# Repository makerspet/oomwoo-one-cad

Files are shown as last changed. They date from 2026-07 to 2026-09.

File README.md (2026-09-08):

<div align="center">

# OOMWOO One CAD

*Open-source robot vacuum you build yourself.*

3D CAD · STEP · 3D printable · Chassis · Mounts · Open hardware





</div>

DIY build instructions [will be posted here](https://makerspet.com/blog/oomwoo-vacuum-build-instructions/). Please visit project home [OOMWOO](https://github.com/makerspet/oomwoo).

## Active work in progress

oomwoo_base_sept_7

side_brush_reverse_engineered

vacuum_assembly_reverse_engineered

## Dock concept

oomwoo_dock_concept

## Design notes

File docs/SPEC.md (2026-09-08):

OOMWOO One open-source vacuum robot spec

A brain-dump with some explanations. First of all, there are 3 living documents

- BOM.md https://github.com/makerspet/oomwoo/blob/main/BOM.md
- Companion article https://makerspet.com/blog/how-to-source-bom-for-oomwoo-open-source-vacuum-robot/
- 3D design spec https://github.com/makerspet/oomwoo-one-cad/blob/main/docs/SPEC.md

All 3D CAD design files live in this repo https://github.com/makerspet/oomwoo-one-cad

Let me go over each component and explain the thinking about it. Please let me know any comments/questions.

I will list the "recommended selection" as well as "backup alternatives".

- "Drive wheel assembly pair". Recommended - reuse Roborock S5 Max wheels because they are abundant in the aftermarket https://makerspet.com/blog/how-to-source-bom-for-oomwoo-open-source-vacuum-robot/#driving-wheels There is a backup alternative - Roborock S5 (non-Max) wheels. These are also abundant, but older. So, don't use those, lets stick with Roborock S5 Max.
- "Caster wheel". Recommended - caster wheel off iRobot Roomba I3/4/6/8, J7/Plus J7 E5/6 500 600 700 800 900 series. It appears to be the most abundant in the aftermarket. iRobot has used the same caster part using in all those models over years. Backup alternatives - plenty available off-the-shelf on AliExpress; or 3D print using TPU.
- "Suction fan". Recommended - BL24131616 10kPa. Recommended for 2nd vacuum version - 36 kPa from Roborock Saros 20, . Backup alternatives - fans with lower suction. Why 10kPa - modern vacuums use increasingly stronger suction. Old vacuums use mere 2-2.5kPa. Users want to see bigger kPa suction.
- "Main brush". Recommended - "Anti-tangle split single roller, rubber and bristles" for Roborock Saros. Users *strongly* want no tangling at all. This roller type seems one of the best - but *I may be wrong*. Another roller that appears to be great is "Anti-tangle hair-cutting dual roller, rubber and bristles", sold as replacement for Dreame vacuums. Please read about roller choices here https://makerspet.com/blog/how-to-source-bom-for-oomwoo-open-source-vacuum-robot/#main-brush Another option is 2 rollers, but having 2 rollers (I assume) will complicate your CAD design. So single (or single split?) roller seems best for 1st vacuum version. The 1st vacuum version's name is OOMWOO One.
- "Battery pack + BMS". Required - the standard Roborock battery. Roborock has been using it over many years and many models. It comes with built-in protection and thermistor. No obvious alternatives.
- "2D LiDAR". Recommended - "PCB mark X-WPFTB-V2.6.2, possibly Camsense". However, there are many alternatives. Some users own different LiDARs - and want to reuse them. So, we should let users pick their LiDAR - by 3D printing a custom mounting bracket.
- "Compute Module". Required - Raspberry Pi CM4 or CM5. CM4 and CM5 have identical dimensions.
- "I/O board". Required - custom-designed PCB https://github.com/makerspet/oomwoo-io-board. The I/O board will have all motor/sensor connectors, driver ICs. The "Compute Module" will plug into the I/O board. The I/O board shape/dimensions is *not* set - it will be decided based on your CAD design.
- "Cliff sensors". Required - "cliff sensor + bumper switches bundle" iRobot Roomba 500 600 700 800 528 552 564 595 560 570 610 615 620 625 630 650 off-the-shelf, abundant in the aftermarket. The "bundle" includes 4 IR cliff sensors and 2 bumper switch assemblies. Backup alternatives - if this bundle doesn't work for you, let me know, I will suggest alternatives. Please note - some vacuums have 4 IR cliff sensors, while others have 6. The typical 4-sensor placement is (1) around the caster wheel (in the front) and in front of each driving wheel. 6-sensor vacuums add one sensor just behind each driving wheel. I've noticed some vacuums have 5 sensors (only one driving wheel has 2 cliff sensors). Generally, I'd like to have 6 cliff sensors, but 6-sensor bundles are harder to find/purchase.
- "Bumper switches". Required - please use the iRobot bundle. If you find a problem using these - let me know.
- "Main brush motor, gearbox". Required - let's use one off Roborock S5 because it is abundant. However, this assembly fits Roborock brushes with bristles (which tangle hair badly). So, you may need to design some sort of adapter to accommodate tangle-free brushes. Backup alternatives - we can buy the DC motor and 3D print gears using an SLA resin printer. But I'd like to avoid this additional complexity if possible. FYI, commercial vacuums use RS390 and RS395 DC motors.
- "Side brush". Recommended - "2-arm curved" side brush from Roborock Saros. It seems better at anti-tangling (but I haven't checked). Backup alternatives - older Roborock side brushes or Dreame side brushes.
- "Side brush motor". Recommended - only one side brush, extendable, from Roborock Qrevo https://www.alibaba.com/product-detail/Roborock-Telescopic-Robotic-Arm-Side-Brush_1601598853246.html Backup alternatives - if the recommended one doesn't work for you, let me know, I will check Dreame X40 and Dreame X50 extendable side brush assemblies.
- "Wall sensor". Required - two little custom-designed PCB (one left, one right). These sensors (1) detect IR signal from the dock (2) detect wall (in a crude way). Backup alternative - a Roborock wall sensor assembly is available on AliExpress, but not abundant.
- "Dock homing sensor". Required - a little custom-designed PCB with two IR sensors, in vacuum rear front. Backup alternatives - let me know if there is a problem and I will check.
- "Carpet sensor". Required - ultrasonic 300kHz material sensor, fixed 30mm distance above floor. This model for your initial CAD design https://www.aliexpress.us/item/3256808845934210.html and this model for volume https://htwsensor.en.made-in-china.com/product/jARpDPKoaxVz/China-300kHz-Carpet-Material-Recognition-Sensor-for-Robotic-Vacuum-Cleaner-Ultraosinc-Sensor-Transducer.h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 .
- "Charging contacts" (on the robot). Recommended - DIY using a nickel-plated steel strip (purchased on AliExpress). Located in the robot's rear around the homing IR sensor PCB. No springs. Strip width/length - up to you. AliExpress has 10-12mm. Each contact (positive, ground) connects to a PCB connector cable. The contact-to-wire connection could be accomplished by designing a tiny 3D printed "terminal'. Have a machine screw pressing the (stripped) wire against the strip.
- "Mop motor assembly". Recommended - 2 rotary/disk mops. One static, one extendable. Use Roborock Qrevo FlexiArm https://www.alibaba.com/product-detail/Mop-Deceleration-Motor-Retractable-Mopping-Module_1601599652498.html Backup alternatives - if the Roborock Qrevo doesn't work for you, I can search Chinese ODM making Dreame MopExtend.
- "Obstacle avoidance camera". Recommended - 1x front-facing OV5647 with a 16-pin flexible cable, ~130 degree FOV. Backup alternatives - none that are cheap.
- Bagless vs bag dock. Recommendation: bagless. Why? Multiple users requested bagless; no-one asked for bags. Also, no consumable bag purchase/cost. The dock's dust bin can be 3D printed. However, bagged is easier to engineer. Bagless needs reliable separation (a working cyclone + washable filter). Designing a good cyclone is important. A poor one sends fine dust straight to the filter, clogs the filter, and suction dies.
Auto-empty design. Recommendation: bottom extraction (Roborock style). Why? This is what my Claude says:
- side brush with extensible arm assembly - expensive, hard to find retail. Roborock uses lots of gears; the brush DC motor both actuates the brush and the arm. Design from scratch using a little timing belt, aluminum timing pulleys and a geared DC motor (metal gearbox comes with the motor). 3D-print the assembly enclosure This avoids having to 3D print gears and keeps the build inexpensive.

=== Claude =====================================

1. Gravity is on your side. Dust settles to the bottom of the bin, and bottom extraction pulls it downward into the dock bin. A dedicated side/rear vent higher on the bin fights gravity — you're asking the fan to lift settled dust before it can carry it out.
2. Simplest robot-side port: one flap. You add a single spring/gravity trap door on the bin bottom — no second sealed opening in the bin. A dedicated vent means a second aperture you must seal against leaks during every vacuuming run.
3. Flat, forgiving dock mating. The dock side is just a gasketed hole in the base plate; the robot parks over it. Flat-plate-to-flat-plate tolerates alignment error far better than threading a nozzle into a port (which a dedicated vent requires). Your ramp/alcove already gets the robot "close enough," and a broad base port forgives the rest — same philosophy as oversizing the charging pads.
4. Proven and measurable. It's the dominant industry design, so you can study/measure a real Roborock dock to de-risk the printed geometry.
5. It decouples from your crowded rear. Your rear is already busy — vertical contacts + mop wash tray (back-in docking). Putting auto-empty on the underside keeps it spatially separate from that cluster.

The hard part is the same for both: the valve + the airflow path

Whichever port you choose, the real engineering is the flap valve and the makeup-air path, not the port location:

- The flap must do two contradictory things: seal tightly during vacuuming (so the robot's own fan doesn't lose suction through the auto-empty port) yet open freely under the dock's airflow. Bottom extraction makes this natural — the dock's downward suction pulls an inward/downward flap open, and spring + gravity reseat it. A high side/rear port needs a more deliberate valve.
- You must give the emptying airflow a makeup-air inlet, or the dock fan just pulls a vacuum against a sealed bin and moves nothing. The clean trick (and what Roborock does): let the dock's suction draw makeup air in through the robot's own intake mouth — which is right there at the bottom — so air sweeps through the bin and out the bottom port, entraining settled dust on the way. Design the bin so that emptying airflow traverses the whole bin volume rather than short-circuiting between two nearby openings. This is the single thing that determines whether auto-empty actually evacuates dust vs. just whistling.

Why not the dedicated bin vent

- Its only real advantage is a seal that's higher and away from floor-level dust. That's outweighed by: a second aperture to seal, a nozzle-to-port mating that's alignment-fussy, fighting gravity, and more total seals — all worse for a printed part where every seam is a potential leak. Not worth it.

Two build-specific notes

- Bagless synergy: bottom extraction drops dust straight down into the dock's printed bin sitting in the base — exactly what you want for the bagless, printed-container design you chose. Gravity does half the work of separating debris before the dock cyclone/filter even acts.
- Since the robot backs in rear-first (mop-dock orientation), position the dock base's suction hole under wherever the robot's bottom bin-port ends up in the docked position — likely forward of the mop/contact cluster. This is part of the same frozen dock interface as the contacts and the beacon, across all three tiers.

So: pull from underneath through a single bottom trap-door, let makeup air come in via the robot's intake so the flow sweeps the bin, and drop it into the printed dock bin by gravity. The dedicated-vent approach adds sealing complexity for a benefit you don't need.

Following modern (2026) consumer mop robot design, OOMWOO One requires

- one right front side brush (not two), with an extendable arm (swings out to the side to clean under cabinets)
- mop is 2-disk rotary (not roller for now); the right mop is extendable (swings out to the side to clean under cabinets); the left mop is fixed
- mop disks land into the dock tray (for mop washing, drying)
- having charging contacts on the *rear vertical face*
  - charging contacts cannot be on the robot's underside because this is where the mop wash tray sits
- vacuum *backing* into the (wash) dock (not driving in front-first)
- robot's dock homing sensor must be on the *rear vertical face* between the charging contacts
- robot's charging contacts are "dumb" (not spring-loaded), use an nickel-plated steel strip
  - nickel-plated steel strips resist corrosion, scratching
- charging contacts on the dock have to be spring loaded, with gold-plated pogo pins, 4A 20.1V to provide 65W
- TODO bagless or not
- LiDAR must be inset 10+cm from vacuum's enclosure edges
  - because LiDAR sensor has a ~10cm dead zone around it
- place LiDAR slightly off-vacuum-center
  - this allows capturing scans from new viewpoints while vacuum spins in-place without getting stuck (usually when lost to regain its whereabouts on the map)
- need to lift mops (when traveling over carpet) 12mm
- need a [carpet sensor](https://makerspet.com/blog/how-to-source-bom-for-oomwoo-open-source-vacuum-robot/#carpet-sensor) (ultrasonic ~300kHz) placed in front of main brush; carpet detect causes mops to lift, stop spinning, main brush to spin appropriately for carpet
  - carpet sensor detects carpet ahead of time as the vacuum travels forward, so the mop is always lifted over carpet
- need 2 side wall sensors (left, right)
  - wall sensors detect dock presence (by receiving IR signal from the dock) and act as a crude wall following (intensity based) sensor
  - wall sensor has to be a small custom PCB
- drving wheels should be centered, wide apart
  - let's try reusing [Roborock S5 Max assembly](https://makerspet.com/blog/how-to-source-bom-for-oomwoo-open-source-vacuum-robot/#driving-wheels) because it is abundant in the aftermarket
  - each wheel comes with a wheel drop sensor (a microswitch)
  - FYI some vacuums don't center driving wheels exactly
- robot-to-floor gap is largely defined by the drive wheels
- caster wheel - front center
  - let's try reusing the abundant [iRobot Roomba](https://makerspet.com/blog/how-to-source-bom-for-oomwoo-open-source-vacuum-robot/#caster-wheel)
- I/O board and compute module - front center top, shape TBD
  - board has pushbuttons
- battery pack - reuse abundant standard [Roborock battery pack](https://makerspet.com/blog/how-to-source-bom-for-oomwoo-open-source-vacuum-robot/#battery-pack)
  - place battery pack on the vacuum bottom, with an access door with screws, roughly under the I/O board or slightly behind, roughly centered to equalize pressure on both wheels and mops
  - TODO check if battery should be close to mops for cleaning pressure

## Dock

### Specs

- ~use an external certified 24 V DC brick (200–350 W)~
  - the dock only sees 24V?
  - inherit the brick's UL/CE certification?
  - ~reuse 25.2 V stick-vac motors, e.g. Dreame M10-E-4 (25.2 V, 310 W) handheld motor, use for auto-empty~
- power 1600W, see [X20 dock teardown](docs/dock_teardown_x20.pdf)
- ~dock contains USB PD sink, converts power to 20-24V charger contacts~
  - dock charger contacts check for robot's presence (resistance), enable power only when robot is present
- skip hot air dry, use a regular fan
  - Hot air dries the mop in ~2–3 h instead of ~6. But the robot sits docked for hours anyway.
  - Dropping the heater removes your biggest power draw and biggest thermal-safety risk.
- bagless
  - No consumable lock-in. The bin is a printed part.
  - Downside: emptying a dusty bin by hand. The dock bin is far larger than the robot's, so you empty it ~monthly instead of every run. Design a wide opening + lid to limit the dust puff.
  - Bagged is significantly easier to engineer — the bag is the container and the filter, so there's no cyclone to design.
  - Bagless needs real separation (a working cyclone + washable filter), and the cyclone is the main engineering risk of this choice — a poor one sends fines straight to the filter, it clogs, and suction dies.
  - Maybe prototype the auto-empty tier bagged to de-risk the port/sealing/motor work, then move to bagless once you've validated a cyclone geometry. Ship bagless.
- bottom extraction auto-empty
  - why? proven, Roborock style; gravity helps dust fall/evacuate vs non-bagless rise; only one, simple robot-side port, one flap - no sealed opening in the robot's dust bin needed; robot-to-dock flat plate-to-plate gasketed mating is relatively simple vs bagged nozzle-into-the-port mating; frees us space in the robot's rear
- tubing, see [X20 dock teardown](docs/dock_teardown_x20.pdf)
  - water 9mm OD clean, 11mm OD dirty, clean mop spray 6mm OD
  - air auto-empty ID 29mm OD 33mm
- canister present sensors: 2x (clear + dirty water canisters): magnet embedded into canister, hidden hall, see [X20 dock teardown](docs/dock_teardown_x20.pdf)
- water level sensors
  - clear water tank : floaters magnet/hall
- TBD sensors
  - TBD dock-side IR turbidity sensor
  - TBD thermistor + independent thermal fuse
  - TBD dock base leak/flood sensor
- TODO cleaning solution
- TBD hot water mop wash
- TBD hot air mop dry
- safety
  - Mains stays outside (certified brick)?
  - Physically separate wet section from electronics; drip loops, drainage, a dam/lip toward the contacts.
  - Presence-detect the robot, energize charge contacts only when the robot is docked
  - If using heater: redundant thermal cutoff (thermistor + independent thermal fuse), never fan-less.
  - Document as advanced build.

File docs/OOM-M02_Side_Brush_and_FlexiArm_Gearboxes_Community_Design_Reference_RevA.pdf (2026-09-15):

### OOMWOO ONE

# Side Brush & FlexiArm Gearboxes

## OOM-M02-02 / OOM-M02-03 / Community Design Reference

DOCUMENT TYPE
COMMUNITY DESIGN REFERENCE

REVISION
A

DATE

### 15 SEP 2026

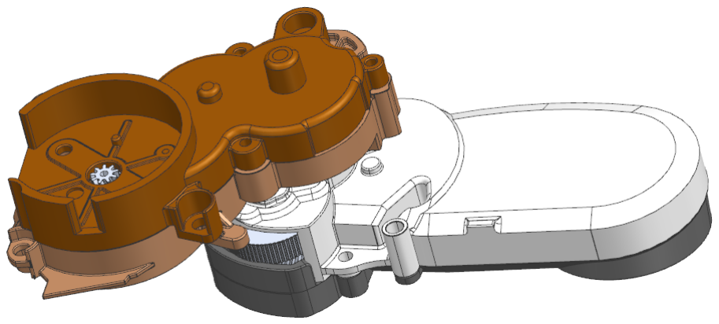
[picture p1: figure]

Figure 1. OOM-M02 side-brush module. The OOM-M02-03 brush gearbox and its motor (upper left, cover removed) are carried on the OOM-M02-02 FlexiArm extendable arm (right). The two housings meet at an angled joint.

Purpose. Explain the two gearboxes inside the OOM-M02 side-brush module for the OOMWOO One community: the OOM-M02-03 three-stage brush reduction (50.248:1), the OOM-M02-02 eleven-gear FlexiArm transfer train (39/14), their gear geometry, compound-axis logic, housing interfaces and the helical stages that carry torque through the arm joint.

COMMUNITY USE / Use this document together with the native CAD and STEP files. The tables explain the design intent and parameter relationships; the current repository CAD remains the master geometry for manufacturing, remixing or modification.

DATA STATUS / Revision A is built from two gear-parameter sheets, two motion studies and annotated CAD screenshots. Values are tagged VERIFIED when they reproduce from the source data, DERIVED when calculated in this document, and CONFIRM when they are an interpretation that must be checked against the CAD. Purchased bearing and bushing content is not identified in the source set and is left open in Section 7.

# 0 About This Design Reference

A practical engineering companion for understanding, rebuilding and modifying the two gearboxes of the OOM-M02 side-brush module.

OOMWOO One is an open-source robot vacuum project intended to be buildable, documented and hackable. The OOM-M02 module carries two independent gear trains with different jobs. OOM-M02-03 turns motor speed into brush speed at a high ratio; OOM-M02-02 routes rotation along the length of the extendable arm and through its angled joint at a ratio close to unity. This reference keeps the two separate so the ratio logic, the compound axes and the housing relationships stay easy to follow.

### How to use this document

Part-code traceability: custom components are identified by the project codes read from the CAD feature trees (Section 1.1). Codes that appear without a role label are listed as observed rather than guessed.
CAD-first reading: tooth counts, modules, pressure and helix angles and centre distances explain the design; the repository CAD/STEP geometry remains the manufacturing master.
Kinematic clarity: each gearbox has its own chain diagram, with compound (coaxial) members marked separately from external meshes so it is clear where torque changes shaft.
Explicit confidence: the three cover tags appear throughout. Nothing that could not be read from the source set is presented as a dimension.
Data review: Section 8 lists three internal inconsistencies found in the parameter sheets. Close those against the CAD before manufacturing or committing a remix.

### Design basis

ID | Design basis | Defines | Use here
B1 | OOM-M02 CAD / STEP set | Gear geometry, housing interfaces, shaft and support features | Manufacturing master
B2 | Gear parameter sheet, 31 AUG 2026 | OOM-M02-03 tooth counts, modules, pressure and helix angles, diameters, centre distances | Sections 2, 3
B3 | Gear parameter sheet, 02 SEP 2026 | OOM-M02-02 eleven-gear mesh list with diameters and centre distances | Sections 4, 5
B4 | Motion study, 01 SEP 2026 | OOM-M02-03 gear train running under a rotary motor driver | Compound-axis confirmation
B5 | Motion study, 03 SEP 2026 | Complete OOM-M02 module with the arm sectioned | Module architecture, joint geometry
B6 | Annotated CAD screenshots | Feature-tree part codes, gear position labels Z1- Z11 | Part numbering, position mapping
B7 | OOM-M03-01 reference, Rev B | Series document conventions and addendum/root formulae | Cross-module consistency

### Contents

Sec. | Topic | Page
1 | Module Architecture & Part Numbering | 3
1.1 | CAD Component Inventory | 4
2 | OOM-M02-03 Gear Train & Kinematics | 5
2.1 | Compound Axes & Load Path | 6
3 | OOM-M02-03 Gear Geometry Reference | 7
4 | OOM-M02-02 Architecture & Mesh List | 8
Sec. | Topic | Page
4.1 | Kinematic Chain & Telescoping Ratio | 9
5 | OOM-M02-02 Gear Geometry Reference | 10
6 | Helical Stages & the Arm Joint | 11
7 | Housing, Shaft & Support Architecture | 12
8 | Parameter-Sheet Consistency Review | 13
9 | Bill of Materials | 14
9.1 | Assembly & Manufacturing Notes | 15
10 | Community Build Notes | 16
10.1 | Open Items & References | 17

•

•

•

•

•

OOMWOO ONE / OOM-M02 SIDE BRUSH & FLEXIARM GEARBOXES

COMMUNITY DESIGN REFERENCE | REV A | 15 SEP 2026 | 2

# 1 Module Architecture & Part Numbering

Two gearboxes, two housings and one angled joint: a high-ratio brush drive carried on a near-unity transfer train that reaches along the extendable arm.

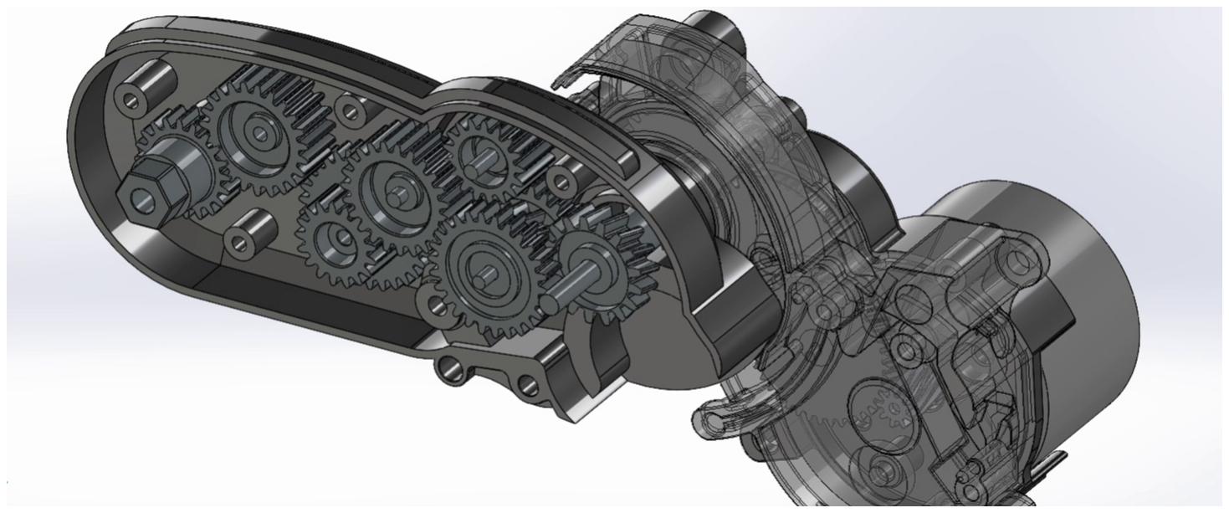
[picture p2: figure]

Figure 2. Complete OOM-M02 module from the 03 SEP motion study. The OOM-M02-02 arm is sectioned to expose its eleven-gear train; the OOM-M02-03 brush gearbox and motor are shown transparent on the right. The gear plane of the arm and the gear plane of the brush module are not parallel, and the helical group sits at that break.

Part code | Designation | Type | Primary role
OOM-M02-01 | Module-level component | Custom part | Top-level member of the module assembly, outside both gear cavities. Role per CAD. CONFIRM
OOM-M02-02 | FlexiArm extendable arm gearbox | Sub-assembly, rev RV02 | Long oval two-shell housing carrying the eleven-gear transfer train Z1-Z11 and the external hex drive interface.
OOM-M02-03 | Side-brush motor gearbox | Sub-assembly, rev rv02 | Brush-side housing carrying the DC motor and the three- stage 50.248:1 reduction Z1-Z6.
OOM-M02-04 | Module-level component | Custom part, rev RV01 | Assembled together with OOM-M02-03 in the brush-side sub-assembly. Role per CAD. CONFIRM

TWO GEARBOXES, ONE MODULE / OOM-M02-03 is a reduction gearbox: three stages, 50.248:1, with the module rising along the train. OOM-M02-02 is a transfer gearbox: seven external meshes on the main branch that telescope to only 39/14 = 2.7857:1. Reading either one as if it were the other type leads to the wrong conclusions about tooth loading and backlash budget.

### Why the arm train is nearly unity

Eleven gears producing less than 3:1 look wasteful until the package is taken into account. The arm has to deliver rotation from one end of a long, slim, swinging housing to the other, then continue through a joint where the two gear planes break at an angle. The intermediate gears exist to relocate the torque path around bosses, the pivot and the housing wall, not to reduce speed. The same pattern appears in OOM-M03-01, where four spur meshes telescope to exactly 1.000 and the whole 3.091:1 comes from the helical input stage alone.
The practical consequence is that the intermediate gears in OOM-M02-02 all see roughly the same torque band, so the weakest tooth anywhere in the chain sets the limit rather than the last one. In OOM-M02-03 the opposite is true: torque rises by a factor of 50 from Z1 to Z6, which is why the module increases from 0.46 mm to 0.60 mm along the train.

# 1.1 CAD Component Inventory

Part codes exactly as they appear in the feature trees, with the gear-position mapping that follows from the tooth counts and instance quantities.

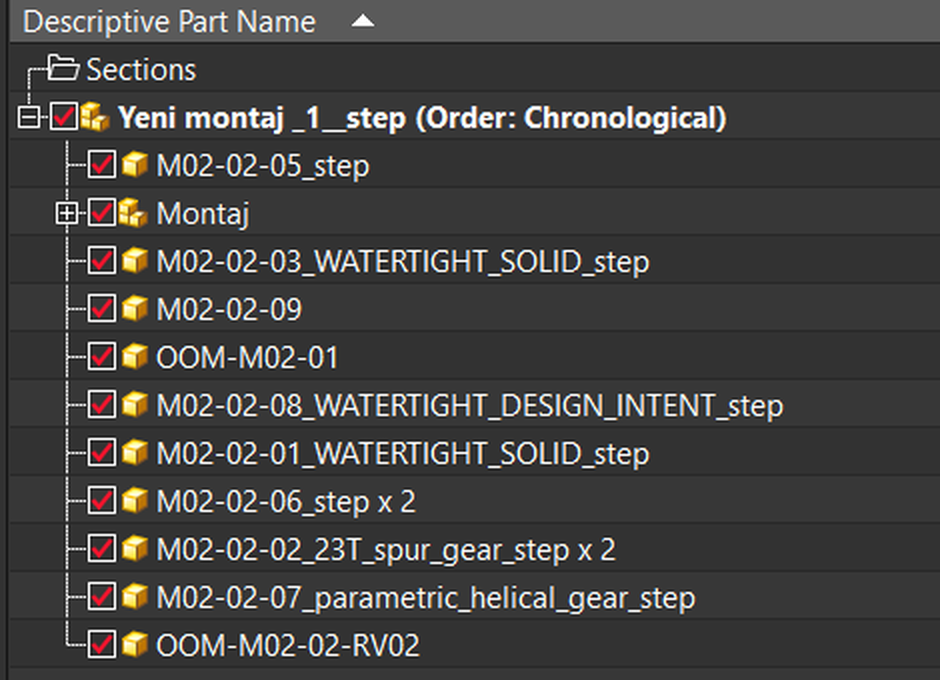
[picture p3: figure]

Figure 3. Component list of the OOM-M02 top-level assembly. Instance counts are significant: two 23T spur gear instances and two M02-02-06 instances match the repeated tooth counts in the parameter sheet.

### OOM-M02-02 FlexiArm gearbox components

Code as modelled | Qty | Read as | Basis
M02-02-01_WATERTIGHT_SOLID | 1 | Housing shell | Watertight reconstructed solid. CONFIRM
M02-02-02_23T_spur_gear | 2 | Z2 and Z5, 23T m0.6 | Only two 23T gears exist in the mesh list. DERIVED
M02-02-03_WATERTIGHT_SOLID | 1 | Housing shell | Second watertight solid. CONFIRM
M02-02-05 | 1 | Per CAD | In the tree with no descriptive suffix. CONFIRM
M02-02-06 | 2 | Z4 and Z6, 17T m0.6 | Only two 17T gears exist in the mesh list. DERIVED
M02-02-07_parametric_helical_gear | 1 | 17T helical, mn
| | 0.76 | Z10 and Z11 are geometrically identical; one parametric body covers both. DERIVED
M02-02-08_WATERTIGHT_DESIGN_INTENT | 1 | Housing / structural solid | Design-intent rebuild, not a scan solid. CONFIRM
M02-02-09 | 1 | Per CAD | In the tree with no descriptive suffix. CONFIRM

### OOM-M02-03 brush gearbox components

Code as modelled | Qty | Read as | Basis
OOM-M02-03-01_design_intent | 1 | Housing, design intent | Gear-cavity shell rebuilt to design intent. CONFIRM
OOM-M02-03-02_SINGLE_SOLID | 1 | Housing / cover | Single-solid counterpart to the shell. CONFIRM
OOM-M02-03-03_1_motor | 1 | DC motor | Model identification not stated in the source set. CONFIRM
OOM-M02-03-03_2_helical_gear | 1 | Z1 motor pinion, 9T | The only helical pinion in the train; mn 0.46, beta 18 deg. VERIFIED
0,5m z11 | 1 | Z3, 11T m0.5 | Name states module 0.5 and 11 teeth, matching Z3. VERIFIED

PART-CODE READING / The gear labels Z1-Z6 (brush gearbox) and Z1-Z11 (arm gearbox) restart independently in each parameter sheet. OOM-M02-02 Z1 is the 20T hex-drive spur gear; OOM-M02-03 Z1 is the 9T helical motor pinion. Always qualify a Z number with its module code.

# 2 OOM-M02-03 Gear Train Design & Kinematics

A helical motor stage followed by two spur stages on two compound axes, with all three reductions stacking to 50.248:1 inside the brush-side housing.
50.248 : 1

OVERALL REDUCTION
motor to brush output

1.990 %

OUTPUT SPEED
of motor speed

# Opposite

ROTATION
motor vs. output

Figure 4. OOM-M02-03 kinematic chain. Z2/Z3 and Z4/Z5 are compound members: each pair shares one axis, so all three ratios multiply.

### Stage-by-stage ratio and centre distance

Stage | Mesh | Teeth | Module | Driven/driver | Centre distance | Function
Z1 -> Z2 | Helical | 9 -> 40 | mn
| | | 0.46 | 40/9 = 4.4444 | 11.850 mm | Primary reduction from the motor shaft
Z2 / Z3 | Compound axis | 40 / 11 | 0.46 / 0.5 | 1.000 | Same axis | Rigid coaxial transfer, helical to spur
Z3 -> Z4 | Spur | 11 -> 38 | m 0.5 | 38/11 = 3.4545 | 12.250 mm | Second reduction
Z4 / Z5 | Compound axis | 38 / 11 | 0.5 / 0.6 | 1.000 | Same axis | Rigid coaxial transfer, module step-up
Z5 -> Z6 | Spur | 11 -> 36 | m 0.6 | 36/11 = 3.2727 | 14.100 mm | Final reduction to the brush output

All three documented centre distances reproduce exactly from a = (d1

+ d2

) / 2 with no centre-distance modification. VERIFIED

### Ratio arithmetic

i

total = (z2

/z1

| ) x (z4 /z3 ) x (z6 /z5

) = (40/9) x (38/11) x (36/11) = 54720 / 1089 = 6080 / 121 = 50.2479
nout / nin = 121 / 6080 = 1.9901 % | 3 external meshes (odd), so the output turns opposite to the motor.

MODULE LADDER / The three stages use three different modules - 0.46, 0.50 and 0.60 mm - increasing in the direction of rising torque. When remixing, do not normalise them to one module: that would change every centre distance and the housing journal positions with them.

OOM-M02-03 · KINEMATIC CHAIN | 3 stages / 2 compound axes

(40/9) x (38/11) x (36/11) = 6080/121 = 50.248 : 1 3 external meshes (odd) → output reverses

# 2.1 Compound Axes & Load Path

The 01 SEP motion study settles the question the parameter sheet cannot answer on its own: which gears share a shaft.

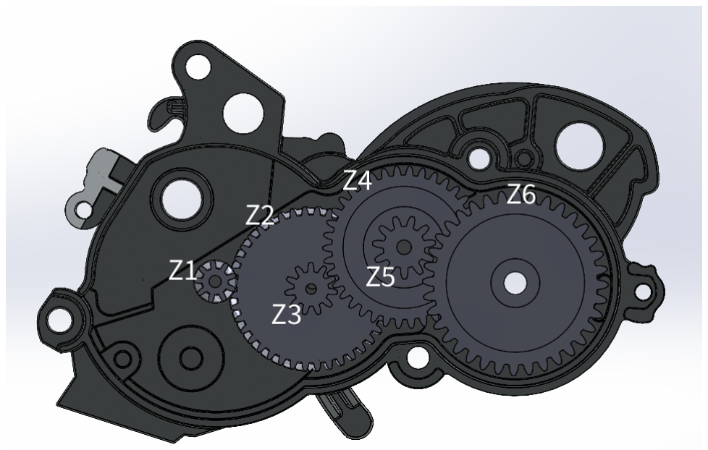
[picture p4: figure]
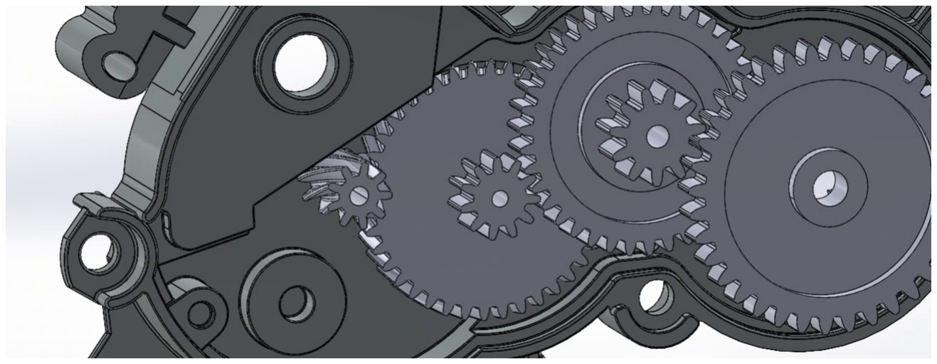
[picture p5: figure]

Figure 5. Left: OOM-M02-03 gear positions Z1-Z6 in the housing, running left to right. Right: frame from the motion study. The small spur pinions sit concentric with the large wheels behind them, which is the visual signature of the Z2/Z3 and Z4/Z5 compound members.

The parameter sheet lists three meshes but does not state how they connect. Three meshes among six gears can be wired as one chain with two compound axes, or as three unrelated pairs. Only the first reading produces a connected train, and the motion study confirms it directly: driving the motor axis turns all six gears, and each small pinion turns at exactly the speed of the large wheel behind it.

Axis | Members | Speed | Design consequence
Motor / Z1 | Z1 9T helical pinion on the motor shaft | Input speed | Radial load plus helical axial thrust. Keep pinion overhang short and preserve motor axial retention.
Z2 / Z3 | 40T helical wheel + 11T m0.5 pinion | Input / 4.4444 | First kinematic hinge. Helical thrust generated at Z1-Z2 is reacted here, so this axis needs a positive thrust path as well as radial support.
Z4 / Z5 | 38T m0.5 wheel + 11T m0.6 pinion Input / 15.354 | Pure spur loading: radial separating force only, but torque is
| | | already 15x motor torque.
Z6 / output | 36T m0.6 output gear | Input / 50.248 | Full output torque plus the external brush reaction. Highest- load support in the module.

### Load-path summary

Motor torque enters at Z1, is multiplied 4.444 times at the helical mesh, passes coaxially from Z2 to Z3, is multiplied again at Z3-Z4 and Z5-Z6, and leaves through the Z6 axis to the brush. The housing absorbs the radial separating force at each of the three meshes, the helical thrust at the first stage only, and the external brush reaction at the output journal. Because torque rises monotonically, the Z6 journal and the Z4/Z5 axis are the two supports worth inspecting first after a run-in test.

THRUST IS LOCAL / Only the Z1-Z2 mesh is helical, so axial thrust exists on the motor axis and the Z2/Z3 axis and nowhere else. The two downstream spur stages need axial clearance to avoid face rub, not axial preload.

# 3 OOM-M02-03 Gear Geometry Reference

Documented tooth parameters, derived helical-system relationships and involute reference values for CAD recreation or cross-checking.

### Helical input stage - Z1 / Z2

Gear | z | mn | Pressure angle | Helix | Pitch d | Outside da | Root df | db
| | | | | | | | at 25° | db at 20°
Z1 motor pinion | 9 | 0.460 | 25 deg | 18 deg | 4.353 | 5.273 | 3.203 | 3.909 | 4.066
Z2 helical wheel | 40 | 0.460 | 20 deg | 18 deg | 19.347 | 20.267 | 18.197 | 17.371 | 18.069

### Spur transfer gears - Z3 through Z6

Gear | z | Module | Pressure angle | Pitch d | Outside da | Root df | db
| | | | | | | | at 25° | db at 20°
Z3 on Z2 axis | 11 | 0.500 | 25 deg | 5.500 | 6.500 | 4.250 | 4.985 | 5.168
Z4 | 38 | 0.500 | 20 deg | | 19.000 | 20.000 | 17.750 | 17.220 | 17.854
Z5 on Z4 axis | 11 | 0.600 | 25 deg | 6.600 | 7.800 | 5.100 | 5.982 | 6.202
Z6 output | 36 | 0.600 | 20 deg | | 21.600 | 22.800 | 20.100 | 19.576 | 20.297

Pitch, outside and root diameters are as documented and reproduce exactly VERIFIED . Base circles are calculated here; the parameter sheet lists base circle equal to pitch circle, which cannot be correct for a non-zero pressure angle (Section 8). DERIVED

HELICAL-SYSTEM INTERPRETATION / The documented pitch diameters satisfy d = mn

z / cos(beta), so 0.460 mm behaves as a normal module. With beta = 18 deg the derived transverse module is mt

= 0.4837 mm. Treating the pressure angle as normal gives a transverse pressure angle of 26.12 deg for a 25 deg normal angle, or 20.94 deg for a 20 deg normal angle. Preserve the native CAD helix hand and tooth form when remaking the pair.

### Reading the diameter data

For the spur stages the pitch diameters follow d = m z, the outside diameters follow da

= d + 2m, and the documented root diameters follow df

= d - 2.5m. This is the same tooth-proportion system used in OOM-M03-01, so the two modules share one convention.
For the helical pair the same offsets are applied using the 0.46 mm normal module while the pitch diameter is enlarged by 1 / cos(beta) = 1.0515.
Both base-circle columns are given because the parameter sheet assigns 25 deg to each pinion and 20 deg to each wheel. A mesh must use one common pressure angle, so exactly one column applies to any given pair. Read the correct value from the CAD tooth profile and then use that column throughout.
The 11-tooth pinions need no undercut relief at 25 deg. At 20 deg, 11 teeth sits below the classical 14-tooth undercut limit for a standard rack-generated profile, which is a further reason to settle the true pressure angle before remanufacturing.
Two gears carry two different modules on one body: Z2/Z3 pairs mn

0.46 with m 0.5, and Z4/Z5 pairs m 0.5 with m 0.6. Treat each compound as a single functional part even if it is modelled as two solids.

•

•

•

•

•

# 4 OOM-M02-02 Architecture & Mesh List

Eleven gears, eight meshes and nine axes inside the arm: a spur transfer path along the housing followed by a three-gear helical group at the joint.
2.7857 : 1

TELESCOPED RATIO
39/14, main branch

35.90 %

OUTPUT SPEED
of drive-axis speed

## 9 axes / 8 meshes

TOPOLOGY
two compound members

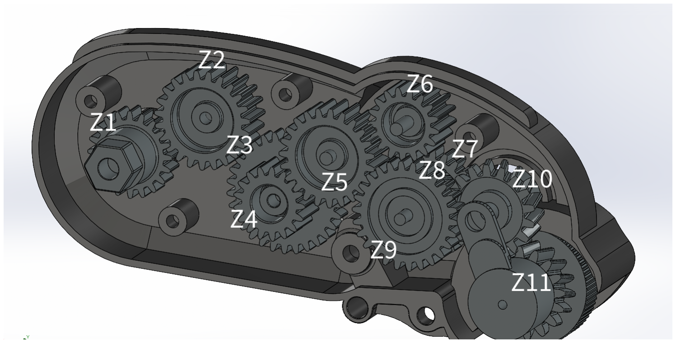
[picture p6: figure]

Figure 6. OOM-M02-02 gear positions Z1-Z11. Z1 carries the external hex form at the wide end of the arm; the Z8/Z10/Z11 helical group sits at the narrow end where the housing breaks toward the brush module.

### Documented mesh list

Mesh | Type | Teeth | Ratio | a documented | a recomputed | Note
Z1 - Z2 | Spur | 20 - 23 | 1.1500 | 11.900 mm | 12.900 mm | Mismatch of exactly 1.000 mm; Section
8. CONFIRM
Z2 - Z3 | Spur | 23 - 30 | 1.3043 | 15.900 mm | 15.900 mm | Exact VERIFIED
Z4 - Z5 | Spur | 17 - 23 | 1.3529 | 12.000 mm | 12.000 mm | Exact VERIFIED
Z5 - Z6 | Spur | 23 - 17 | 0.7391 | 12.000 mm | 12.000 mm | Exact VERIFIED
Z6 - Z7 | Spur | 17 - 26 | 1.5294 | 12.900 mm | 12.900 mm | Exact VERIFIED
Z5 - Z9 | Spur | 23 - 26 | 1.1304 | 14.700 mm | 14.700 mm | Second branch off the Z5 axis VERIFIED
Z8 - Z10 | Helical | 14 - 17 | 1.2143 | 12.196 mm | 12.196 mm | Exact VERIFIED
Z10 - Z11 | Helical | 17 - 17 | 1.0000 | 13.376 mm | 13.376 mm | Unity pair, pure relocation VERIFIED

WHY THE COMPOUND AXES MATTER / Eight meshes among eleven gears leave the train disconnected unless two gear pairs share axes. Only one assignment makes the graph connected - Z3 with Z4, and Z7 with Z8 - and it is the same assignment the tooth counts and instance quantities suggest. Remove either compound and the arm becomes two or three unconnected gear groups in one housing, which the 03 SEP motion study rules out. These two assumptions carry Sections 4.1 and 5, so verify them first in the CAD.

# 4.1 Kinematic Chain & Telescoping Ratio

Seven external meshes on the main branch collapse to a single fraction, 39/14, because four of the eight tooth counts cancel in pairs across the Z5 axis.

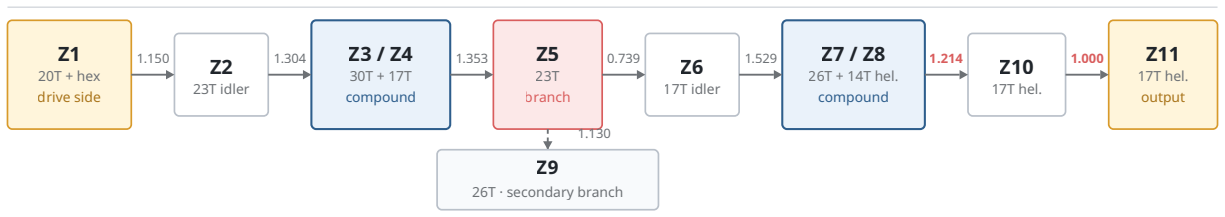
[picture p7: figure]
Z1 20T + hex drive side; Z2 23T idler; Z3 / Z4 30T + 17T compound; Z5 23T branch; Z6 17T idler; Z7 / Z8 26T + 14T hel. compound; Z10 17T hel.; Z11 17T hel. output; Z9 26T · secondary branch

Figure 7. OOM-M02-02 kinematic chain. The chain is a branched tree: Z5 splits the path toward the joint group and toward Z9. Drive direction is discussed below.

imain = (23/20)(30/23)(23/17)(17/23)(26/17)(17/14)(17/17) = (30/20) x (26/14) = 39/14 = 2.7857
ibranch = (23/20)(30/23)(23/17)(26/23) = (30/20) x (26/17) = 39/17 = 2.2941

Only three tooth counts survive: 20 and 30 on the first compound, and 26 with 14 on the second. Every other gear in the arm is a pure relocation member. Z2, Z5, Z6 and Z10 change nothing about the ratio; they carry torque past housing features and set where each axis lands. Z10-Z11 is a unity pair, so the last helical mesh exists purely to move the axis.

### Axis map

Axis | Members | Meshes | Role
A1 | Z1, 20T m0.6 + external hex form | 1 | External drive interface at the wide end of the arm.
A2 | Z2, 23T m0.6 | 2 | Idler; relocates the path past the first housing boss.
A3 | Z3 30T + Z4 17T, compound | 2 | First compound member and the only source of the 30/20 factor. DERIVED
A4 | Z5, 23T m0.6 | 3 | Branch point: feeds Z6 toward the joint and Z9 on the secondary branch.
A5 | Z6, 17T m0.6 | 2 | Idler between the branch point and the joint group.
A6 | Z7 26T spur + Z8 14T helical, compound | 2 | Second compound member and the spur-to-helical handover; source of the 26/14 factor. DERIVED
A7 | Z10, 17T helical | 2 | Helical idler inside the joint region.
A8 | Z11, 17T helical | 1 | End of the main branch; carries the link interface visible in the CAD. CONFIRM
A9 | Z9, 26T m0.6 | 1 | End of the secondary branch. Function not stated in the source set. CONFIRM

DRIVE-DIRECTION READING / The source set does not state which end of the arm is driven. This document presents the chain in the Z1 -> Z11 direction, where the external hex form on Z1 acts as the input coupling and the train reduces 2.7857:1 toward the joint. If the CAD shows drive entering at the helical group instead, the identical chain reads as a 1 : 2.7857 step-up and the two interface roles swap. Every tooth count, centre distance and diameter in Sections 4 and 5 is unaffected either way; only the ratio direction and the torque grading change. Close this first, because it decides which tooth in the chain is the weakest. CONFIRM

OOM-M02-02 · KINEMATIC CHAIN | 8 meshes / 9 axes / 2 compound axes

Main branch Z1 → Z11 = 39/14 = 2.7857 : 1 Secondary branch Z1 → Z9 = 39/17 = 2.2941 : 1

7 meshes (odd) → main output reverses 4 meshes (even) → Z9 keeps the drive sense

# 5 OOM-M02-02 Gear Geometry Reference

One spur system at m 0.6 for the eight transfer gears, one helical system at mn

0.76 and beta 15 deg for the three joint gears.

### Spur transfer gears - m 0.6

Gear | z | Module | Pressure angle | Pitch d | Outside da | Root df | db
| | | | | | | at 25° | db
| | | | | | | | at 20° | Position
Z1 | 20 | 0.600 | 20 deg | 12.000 | 13.200 | 10.500 | 10.876 | 11.276 | Hex drive axis
Z2 | 23 | 0.600 | 20 deg | 13.800 | 15.000 | 12.300 | 12.507 | 12.968 | Idler
Z3 | 30 | 0.600 | 20 deg | 18.000 | 19.200 | 16.500 | 16.314 | 16.915 | Compound with Z4
Z4 | 17 | 0.600 | 25 deg | 10.200 | 11.400 | 8.700 | 9.244 | 9.585 | Compound with Z3
Z5 | 23 | 0.600 | 20 deg | 13.800 | 15.000 | 12.300 | 12.507 | 12.968 | Branch point
Z6 | 17 | 0.600 | 25 deg | 10.200 | 11.400 | 8.700 | 9.244 | 9.585 | Idler
Z7 | 26 | 0.600 | 20 deg | 15.600 | 16.800 | 14.100 | 14.138 | 14.659 | Compound with Z8
Z9 | 26 | 0.600 | 20 deg | 15.600 | 16.800 | 14.100 | 14.138 | 14.659 | Secondary branch

### Helical joint gears - mn

### 0.76, beta 15 deg

Gear | z | mn | Pressure angle | Helix | Pitch d | Outside da | Root df | db
| | | | | | | | at 25° | Position
Z8 | 14 | 0.760 | 25 deg | 15 deg | 11.015 | 12.535 | 9.115 | 9.920 | Compound with Z7
Z10 | 17 | 0.760 | 25 deg | 15 deg | 13.376 | 14.896 | 11.476 | 12.046 | Helical idler
Z11 | 17 | 0.760 | 25 deg | 15 deg | 13.376 | 14.896 | 11.476 | 12.046 | Main branch end

Geometry columns reproduce exactly from the parameter sheet, including the 25 / 20 deg pressure-angle split in the spur set VERIFIED . Base circles are calculated here DERIVED .

HELICAL-SYSTEM INTERPRETATION / The documented pitch diameters satisfy d = mn

z / cos(beta), so 0.760 mm behaves as a normal module. With beta = 15 deg the derived transverse module is mt

= 0.7868 mm and, treating 25 deg as the normal pressure angle, the transverse pressure angle is 25.77 deg. All three helical gears carry the same pressure angle in the source data, so this group needs no pressure-angle resolution - unlike the spur set.

### Distinct-part summary

Distinct geometry | Qty | Positions
20T m0.6 spur + hex | 1 | Z1
23T m0.6 spur | 2 | Z2, Z5
30T m0.6 spur | 1 | Z3
17T m0.6 spur | 2 | Z4, Z6
26T m0.6 spur | 2 | Z7, Z9
14T helical mn
0.76 | 1 | Z8

17T helical mn

0.76 | 2 | Z10, Z11

Seven distinct geometries cover eleven installed gears, which matters when planning a print run or a spare set. Four of the eight spur gears are only two distinct parts.
Whether Z3+Z4 and Z7+Z8 are moulded as single compound bodies or stacked as two parts on a shared shaft is a CAD question. The instance counts in Figure 3 point to stacked separate parts: the two M02-02-06 instances account for Z4 and Z6, which leaves no spare 17T body for a one-piece Z3/Z4 compound. If they are separate parts, the rotational lock between them is a load-path element rather than a convenience. CONFIRM

# 6 Helical Stages & the Arm Joint

Both gearboxes use helical teeth, and in both cases the reason is geometric rather than acoustic.

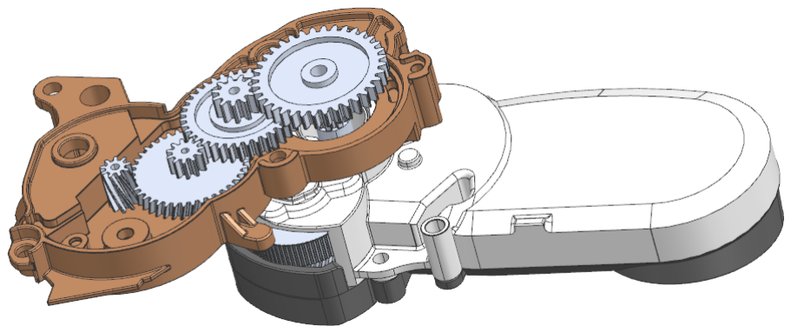
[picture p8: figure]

Figure 8. The brush gearbox opened on the arm. The brush-side gear plane and the arm-side gear plane are set at an angle to each other, and the helical group bridges that break.

### The two helical systems compared

Property | OOM-M02-03, Z1 / Z2 | | OOM-M02-02, Z8 / Z10 / Z11
Normal module | 0.460 mm | | 0.760 mm
Helix angle | 18 deg | | 15 deg
Transverse module | 0.4837 mm DERIVED | | 0.7868 mm DERIVED
Transverse pressure angle | 26.12 deg at 25 deg normal, 20.94 deg at 20 deg normal 25.77 deg at 25 deg normal
Helical meshes | 1 | 2
Ratio contribution | The full 4.4444 of the first stage | | 1.2143 at Z8-Z10, exactly 1.000 at Z10-Z11
Design reason | Quiet, high-ratio first stage directly on the motor shaft,
where speed is highest and torque lowest
| | | Carries rotation through the angled break between the arm and the brush module

### Parallel or crossed axes?

Reading | Helix hands | Shaft angle | Consequence
Parallel-axis helical | Opposite hands, 15 deg each | 0 deg | Conventional line contact, high load capacity, thrust reacted axially on each shaft. All three axes stay in one plane.
Crossed-axis helical | Same hand, 15 deg each | 30 deg | Point contact, much lower load capacity and higher sliding velocity, but the drive turns through 30 deg without a bevel or worm. Matches the visible plane break in Figures 2 and 8.

Both readings satisfy a = (d1

+ d2

) / 2 with d = mn

z / cos(beta), which is why the documented centre distances cannot distinguish them. What does distinguish them is the helix hand of each gear and the relative orientation of the three axes in the CAD.

HAND AND SHAFT-ANGLE RULE / Read the helix hand of Z8, Z10 and Z11 directly from the native CAD before remaking any of them. If the group is crossed-axis at 30 deg the contact is point contact, and the face width, material pairing and lubrication decisions all change. A part that is dimensionally correct but handed wrong will mesh, run, and then fail early. CONFIRM

### Thrust bookkeeping

OOM-M02-03: thrust exists on the motor axis and on the Z2/Z3 compound axis. Both need a defined thrust reaction face; the two downstream spur axes need axial clearance only.
OOM-M02-02: thrust exists on the Z7/Z8 compound axis and on the Z10 and Z11 axes. The Z7/Z8 member is critical because it carries a spur mesh and a helical mesh at the same time, so its support takes a radial separating force and an axial thrust simultaneously.
In a crossed-axis reading the thrust direction on Z10 and Z11 changes relative to the parallel case, which is a second reason to close the hand question before detailing the supports.

•

•

•

# 7 Housing, Shaft & Support Architecture

What the source set establishes about the load path, and what it deliberately leaves open.

In OOM-M03-01 the support hardware was annotated in the CAD views, so that document could name an MR106ZZ ball bearing, a JSM-1416-05 polymer sleeve and an AMC30604 Oilite bush. The OOM-M02 source set carries no equivalent annotation. What the screenshots and motion studies do establish is the support concept at each axis: integral moulded posts and journal bosses in the housing shells, with a two-shell closure that traps the gear stack axially.

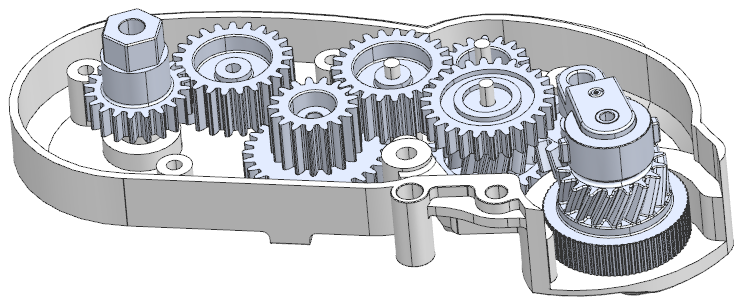
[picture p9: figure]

Figure 9. OOM-M02-02 gear set seated in the lower shell. The integral moulded posts are visible between the gears, the hex form sits on the Z1 axis at the left, and the helical group with its link interface is at the lower right, tilted out of the main gear plane.

### Support concept by axis

Gearbox | Axis | Support concept observed | Load-path interpretation
M02-03 | Motor / Z1 | Motor internal bearings; pinion on the motor shaft | Radial load plus helical axial thrust. Keep pinion overhang short.
M02-03 | Z2 / Z3 | Fixed post or journal in the shells | First kinematic hinge; play here affects the motor mesh and the whole downstream path.
M02-03 | Z4 / Z5 | Fixed post or journal in the shells | Spur loading only, at roughly 15x motor torque.
M02-03 | Z6 / output | Output journal through the housing to the brush interface | Full output torque plus the external brush reaction. Gear-to-coupling concentricity must survive housing closure.
M02-02 | Z1 hex axis | Journal with an external non-circular form | Positive torque transfer rather than friction. Concentricity of gear and hex is the controlling requirement.
M02-02 | Z2, Z5, Z6, Z9 | Integral moulded posts in the lower shell | Idler and branch axes. Post diameter and perpendicularity set the centre distances.
M02-02 | Z3 / Z4 | Shared shaft or post carrying both gears | Ratio-bearing compound. If the gears are separate parts, the lock between them is a load-path element.
M02-02 | Z7 / Z8 | Shared shaft at the spur-to-helical handover | Simultaneous radial separating force and helical thrust. The most demanding support in the arm.
M02-02 | Z10, Z11 | Journals in the angled joint region; link interface on Z11 | Helical thrust plus the external link reaction. Joint stiffness directly affects mesh contact.

Support concepts are read from the CAD screenshots and motion studies. No purchased bearing or bushing part numbers, shaft diameters, lengths or fits are stated in the source set. CONFIRM

### Key geometric relationships

Every centre distance is created by the housing post and journal locations. Print shrinkage or fit tuning must not move those axes independently of each other.
Axial clearance is needed on every rotating gear so that closing the shells does not create face rub. Helical members additionally need a defined thrust reaction path in one direction.
The compound axes are the kinematic hinges of their trains. Angular or radial play at a compound axis propagates both upstream and downstream, unlike play at an idler.
Treat every support as one tolerance chain: shaft or hub diameter, housing seat, axial retention and running clearance have to stay compatible. Use the CAD for support lengths and axial stack-up.
Both housings are two-shell designs whose perimeter register preserves gear-axis spacing after closure, and it should not distort an output journal or remove end clearance.

WHAT TO ADD IN REV B / The highest-value additions to this document are the purchased support hardware per axis, the shaft diameters and lengths, and the helix hands of Z8, Z10 and Z11. Those three items close nearly every open point in Sections 6 and 7.

•

•

•

•

•

# 8 Parameter-Sheet Consistency Review

Three internal inconsistencies were found while cross-checking the two parameter sheets. None of them changes the gear train architecture, and all three should be closed against the CAD before manufacture.

# | Finding | Where | Why it cannot be right as written | Recommended resolution

### 1 Pressure angle split 25 / 20

deg within a single mesh

Every documented pair in
both sheets except the mn
0.76 helical group

Two involute gears run conjugately only if they share one pressure angle in the plane of action. A 25 deg pinion cannot mesh correctly with a 20 deg wheel of the same module.

Read one pressure angle per mesh from the CAD tooth profile, then apply it to both members. Sections 3 and 5 give base circles for both readings, so either resolution is usable immediately.

### 2 Base circle listed equal to

pitch circle

All diameter tables in both sheets: base, pitch and
rolling circle share one
value on every row

db

= d cos(alpha) is strictly smaller than the pitch circle for any non-zero pressure angle. Equality would mean a 0 deg pressure angle.

Treat the base-circle column in the source sheets as unpopulated. This document derives base circles at both 20 and 25 deg for every gear; use those, or regenerate from the CAD.

### 3 Z1-Z2 centre distance 11.900

mm

OOM-M02-02, first
documented pair

For m 0.6 with 20T and 23T, a = (12.000 + 13.800) / 2 = 12.900 mm. No integer tooth count at m 0.6 gives 11.900 mm against a 23T wheel, and the neighbouring Z6-Z7 pair is correctly listed as 12.900 mm.

Read as a transcription error for 12.900 mm. Confirm against the CAD axis positions; if the CAD really shows 11.900 mm, then a tooth count or the module differs from the sheet.

### What did cross-check exactly

All three OOM-M02-03 centre distances (11.850, 12.250, 14.100 mm) reproduce exactly from the tooth counts and modules. VERIFIED Seven of the eight OOM-M02-02 centre distances reproduce exactly; only finding 3 above does not. VERIFIED
Every outside and root diameter in both sheets reproduces exactly from da

= d + 2m and df

= d - 2.5m, including the helical rows using the normal module. VERIFIED
Both helical systems satisfy d = mn

z / cos(beta) to three decimal places, confirming that the tabulated modules are normal modules rather than transverse. VERIFIED
The OOM-M02-02 mesh list forms a connected tree under exactly one coaxial assignment, and that assignment is consistent with the instance counts in the CAD tree. DERIVED

PRIORITY / Finding 1 is the one to close first. It changes base circles, undercut margin on the 11-tooth pinions in OOM-M02-03, tooth thickness and therefore the backlash budget at every mesh. Findings 2 and 3 are bookkeeping by comparison.

•
•
•

•

•

# 9 Bill of Materials

Core parts of both gearboxes, with the items the source set does not identify marked rather than guessed.

### OOM-M02-03 side-brush gearbox

# | Part / code | Description | Qty | Origin | Design detail

1 | OOM-M02-03-01 | Housing, design-intent shell | 1 | Custom CAD | Gear cavity and motor pocket
2 | OOM-M02-03-02 | Housing / cover, single solid | 1 | Custom CAD | Closes the cavity; carries upper
supports
3 | OOM-M02-03-03_2 | Z1 motor pinion, 9T helical | 1 | Custom CAD | mn

0.46, beta 18 deg; motor-shaft input
4 | per CAD | Z2 / Z3 compound: 40T helical + 11T spur | 1 | Custom CAD | mn

0.46 with m 0.5 on one axis

5 | 0,5m z11 | 11T m0.5 spur, Z3 geometry | 1 | Custom CAD | Named in the CAD tree
6 | per CAD | Z4 / Z5 compound: 38T + 11T spur | 1 | Custom CAD | m 0.5 with m 0.6 on one axis
7 | per CAD | Z6 output gear, 36T spur | 1 | Custom CAD | m 0.6; drives the brush interface
8 | OOM-M02-03-03_1 | DC motor | 1 | Purchased | Model per CAD/BOM | CONFIRM
9 | per CAD | Gear shafts / posts, bearings, bushings | per CAD | Per CAD/BOM | Not identified in the source set
CONFIRM

### OOM-M02-02 FlexiArm gearbox

# | Part / code | Description | Qty | Origin | Design detail

1 | M02-02-01 | Housing shell, watertight solid | 1 | Custom CAD | One half of the gear cavity
2 | M02-02-03 | Housing shell, watertight solid | 1 | Custom CAD | Second shell
3 | M02-02-08 | Housing / structural solid, design intent | 1 | Custom CAD | Design-intent rebuild
4 | per CAD | Z1, 20T m0.6 spur with external hex form | 1 | Custom CAD | External drive interface
5 | M02-02-02 | 23T m0.6 spur, Z2 and Z5 | 2 | Custom CAD | Identical parts
6 | per CAD | Z3, 30T m0.6 spur | 1 | Custom CAD | Compound with Z4; ratio-bearing
7 | M02-02-06 | 17T m0.6 spur, Z4 and Z6 | 2 | Custom CAD | Identical parts
8 | per CAD | Z7, 26T m0.6 spur | 1 | Custom CAD | Compound with Z8
9 | per CAD | Z9, 26T m0.6 spur | 1 | Custom CAD | Secondary branch end
10 | per CAD | Z8, 14T helical mn
0.76 | 1 | Custom CAD | beta 15 deg; hand per CAD
CONFIRM
11 | M02-02-07 | 17T helical mn
0.76, Z10 and Z11 | 2 | Custom CAD | Parametric body; hand per CAD
CONFIRM
12 | M02-02-05 / -09 | Components present in the CAD tree | 1 each | Custom CAD | Role per CAD | CONFIRM
13 | per CAD | Gear shafts / posts, bearings, bushings,
link
per CAD | Per CAD/BOM | Not identified in the source set
CONFIRM

Compound members are listed as one line item each because they act as one functional part. Whether a compound is a single moulded body or two gears on a shared shaft is the subject of open item O5. CONFIRM

# 9.1 Assembly & Manufacturing Notes

A practical build sequence for community reproductions, and the parameters most easily lost in a CAD remix.

### Suggested assembly sequence

Inspect all housing journal and post surfaces, gear bores, the motor pocket and the hex interface. Remove only intentional support material or debris from functional surfaces.
Fit the OOM-M02-03 Z1 helical pinion to the motor shaft at the CAD axial position, using a method that does not drive load through the motor bearings.
Seat the motor in the brush-side housing, then place the Z2/Z3 compound so the helical teeth enter mesh without forcing. Install the Z4/Z5 compound, then the Z6 output gear.
Build the arm gear set in the lower shell in axis order: Z1 with its hex form, Z2, the Z3/Z4 compound, Z5, Z6, the Z7/Z8 compound, then Z10 and Z11. Install Z9 last so the branch mesh can be checked on its own.
Verify helix hand and axial position on Z8, Z10 and Z11 before closing the joint region. A wrong hand will still assemble.
Close each housing lightly and rotate each train by hand through several revolutions. Expect motor cogging in the brush gearbox, but no hard interference, housing rub or tight spot in either train.
Tighten each housing evenly using the current CAD/BOM fastener strategy, repeat the rotation check, then begin powered run-in at reduced voltage before full-load use.

### Manufacturing and modification notes

Preserve the helix hand, helix angle, normal module and compound coaxial relationships when moving either gearbox between CAD systems. Helix hand is the parameter most often lost in a STEP round-trip through a rebuild.
Do not normalise the three modules in OOM-M02-03 to a single value. The module ladder is deliberate and every centre distance depends on it.
Do not assume the two 17T gears and the two 23T gears are interchangeable with the compound members. Check bore and hub features, which differ even where the tooth geometry does not.
If journal fits are printed, tune them with process-specific test coupons rather than globally scaling the housing.
Record material, print process, orientation, post-cure and dimensional compensation for gears and housings so another builder can reproduce the same behaviour.
Use only a small amount of compatible gear lubricant if lubrication is required; keep it away from motor commutator openings and any plain-bearing material intended to run dry.

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
# 10 Community Build Notes

A compact inspection checklist for reproducing either gearbox, and the reference numbers to measure against.

### What to look for after assembly

Check | What the builder should observe
Motor alignment | The OOM-M02-03 Z1 pinion should enter the Z2 helical mesh evenly across the intended face width, with no visible skew or end contact.
Helical mesh, brush side | Rotate slowly and confirm there is no hard spot. This stage carries both radial force and axial thrust.
Compound axes | Each compound member should run as one coaxial unit with no wobble between its two gears. Check Z2/Z3 and Z4/Z5 in the brush gearbox, Z3/Z4 and Z7/Z8 in the arm.
Brush output | The Z6 axis should remain concentric with the brush coupling and rotate without rubbing the housing.
Arm transfer path | Z2, Z5, Z6 and Z10 should rotate freely and preserve positive backlash around the full revolution. A tight spot at one angular position usually means a post is out of perpendicular.
Hex interface | The external hex should be concentric with the Z1 gear axis and transfer torque without deflecting the gear.
Joint group | Z8, Z10 and Z11 should mesh across full face width at the modelled shaft angle. Reduced contact at one end points to a hand or shaft-angle error, not a clearance problem.
Secondary branch | Z9 should rotate with Z5 with no added drag. Because it is a dead-end branch, extra friction there is easy to miss in an assembled test.
Housing closure | Fastening either set of shells should not significantly increase rotation torque or create gear-face rub.
Run-in | Start at reduced voltage, record sound and current, then inspect teeth, journals and housing witness marks.
Remix documentation | Record any changed motor, shaft, journal, gear, hex or link dimension so the modified version stays reproducible.

### Design reference measurements

OOM-M02-03 | Reference
Z1-Z2 centre distance | 11.850 mm
Z3-Z4 centre distance | 12.250 mm
Z5-Z6 centre distance | 14.100 mm
Stage ratios | 4.4444 / 3.4545 / 3.2727
Overall ideal ratio | 50.2479 : 1
Output speed | 1.9901 % of motor
Output sense | Opposite to motor
OOM-M02-02 | Reference
Z1-Z2 centre distance | 12.900 mm, Section 8
Z2-Z3 / Z4-Z5 / Z5-Z6 | 15.900 / 12.000 / 12.000
Z6-Z7 / Z5-Z9 | 12.900 / 14.700 mm
Z8-Z10 / Z10-Z11 | 12.196 / 13.376 mm
Main branch ratio | 39/14 = 2.7857 : 1
Secondary branch ratio | 39/17 = 2.2941 : 1
Main output sense | Opposite to drive axis

MEASURE BEFORE ASSUMING / The reference values above are ideal geometry from the parameter sheets, not measured parts. Treat them as the target a printed or machined reproduction should be checked against, and note that the OOM-M02-02 Z1-Z2 value shown is the corrected 12.900 mm rather than the sheet value.

# 10.1 Open Items & References

What this revision could not close from the available source set, and where each answer lives.

### Open items for Revision B

# | Open item | Decides | Where to read it

O1 | Drive direction of OOM-M02-02: hex axis or helical group | Ratio direction, torque grading, weakest tooth | Motor or coupling location in the module CAD; motion-study driver assignment
O2 | Helix hand of Z8, Z10, Z11 and the shaft angle of the joint group | Parallel vs crossed axis, contact type, load capacity | Native CAD gear features and axis orientations
O3 | One pressure angle per mesh | Base circles, tooth thickness, undercut margin, backlash | CAD tooth profile measurement
O4 | Function of the Z9 secondary branch | Whether it is a second output or a sensing / indexing path | What the Z9 axis connects to outside the gear cavity
O5 | Whether the compound members are single bodies or stacked parts | Torque-lock detailing between the two gears | Part structure of the Z3/Z4 and Z7/Z8 axes in CAD
O6 | Purchased support hardware, shaft diameters and lengths | Section 7 tolerance chains | Current CAD/BOM
O7 | Motor identification for OOM-M02-03 | Input speed, torque and thrust budget; achievable brush speed | CAD/BOM motor component
O8 | Roles of OOM-M02-01, OOM-M02-04, M02-02-05 and M02-02-09 | Module-level architecture completeness | Top-level assembly in CAD

### References and project links

[1] OOMWOO One CAD repository - https://github.com/makerspet/oomwoo-one-cad
[2] OOMWOO One CAD 3D design specification - https://github.com/makerspet/oomwoo-one-cad/blob/main/docs/SPEC.md
[3] OOMWOO main project BOM and design documentation - https://github.com/makerspet/oomwoo
[4] OOM-M02-03 gear parameter sheet, 31 AUG 2026 - tooth counts, modules, pressure and helix angles, diameters, centre distances.
[5] OOM-M02-02 gear parameter sheet, 02 SEP 2026 - eleven-gear mesh list with diameters and centre distances.
[6] OOM-M02-03 motion study, 01 SEP 2026 - rotary-motor driven gear train, used for compound-axis confirmation.
[7] OOM-M02 module motion study, 03 SEP 2026 - complete module with the arm sectioned, used for joint geometry.
[8] Annotated CAD screenshots, SEP 2026 - feature-tree part codes and gear position labels Z1-Z11.
[9] OOM-M03-01 Motor Drive Gearbox, Community Design Reference, Rev B, 28 AUG 2026 - series conventions and tooth-proportion formulae.

REPOSITORY NOTE / For current licence terms, contribution guidance, part revisions and manufacturing geometry, use the repository README, LICENSE and native CAD files. This PDF is an explanatory design reference, not a substitute for the current CAD revision.

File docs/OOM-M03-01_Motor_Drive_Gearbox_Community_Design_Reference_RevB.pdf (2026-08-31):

## OOMWOO ONE

# Motor Drive Gearbox

# OOM-M03-01 / Community Design Reference

DOCUMENT TYPE
COMMUNITY DESIGN REFERENCE

REVISION
B

DATE

### 28 AUG 2026

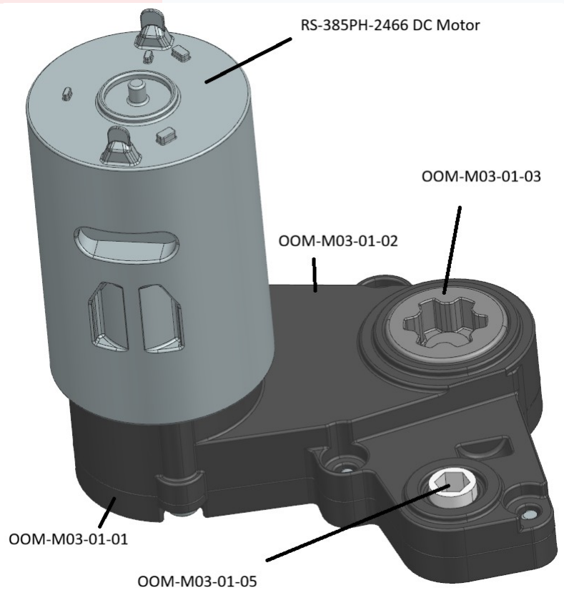
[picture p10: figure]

Figure 1. OOM-M03-01 motor-drive gearbox with RS-385PH-2466 motor, housing part codes and external output interface.
Purpose. Explain the OOM-M03-01 motor gearbox architecture, helical input stage, spur transfer train, housing interfaces and shaft/support logic for the OOMWOO One community.

COMMUNITY USE / Use this document together with the native CAD and STEP files. The tables explain the design intent and parameter relationships; the current repository CAD remains the master geometry for manufacturing, remixing or modification.

OOMWOO ONE / OOM-M03-01 MOTOR DRIVE GEARBOX

COMMUNITY DESIGN REFERENCE | REV B | 28 AUG 2026 | 2

# 0 About This Design Reference

A practical engineering companion for understanding, rebuilding and modifying the OOM-M03-01 gearbox module.

OOMWOO One is an open-source robot vacuum project intended to be buildable, documented and hackable. This reference explains the mechanical logic behind the OOM-M03-01 gearbox so a community member can understand the motion path, identify the custom parts, reproduce the gear parameters and preserve the critical housing/shaft relationships when adapting the module.

## How to use this document

- Part-code traceability: custom components are identified by their OOM-M03-01-xx project codes shown in the annotated CAD views.
- CAD-first reading: dimensions and formulas here explain the design, while the repository CAD/STEP geometry remains the manufacturing master.
- Kinematic clarity: the first helical reduction stage and the following spur transfer path are separated so the ratio logic is easy to follow.
- Interface-first detail: motor mounting, compound-gear coaxiality, housing journals/posts and the output socket are treated as mechanical interfaces rather than isolated parts.
- Purchased-hardware traceability: bearings, bushings and shaft diameters identified in the annotated housing views are documented in Section 6 and the BOM. Axial lengths, material choices and any unlabelled fit details remain controlled by the current CAD/BOM.

## Design basis

ID | Design basis | Defines | Use in this document
B1 | OOM-M03-01 CAD / STEP | Gear geometry, housing interfaces and output coupling | Manufacturing master
B2 | Annotated CAD figures | Part codes, motor model and assembly orientation | Visual orientation
B3 | OOMWOO One CAD / project documentation | Open-hardware context and gearbox sourcing philosophy | Project context
B4 | Motor reference data | RS-385PH family and exact RS-385PH-2466 12 V identification | Purchased motor context

## Contents

Sec. | Topic | Page
1 | Assembly Architecture & Part Numbering | 3
2 | Gear Train Design & Kinematics | 4
3 | Gear Geometry Reference | 5
4 | Top Housing & Output Interface | 6
5 | Bottom Housing & Motor Interface | 7
6 | Shaft, Bearing, Bushing & Load-Path Architecture | 8
7 | BOM, Assembly & Manufacturing Notes | 11
8 | Community Build Notes & References | 12

# 1 Assembly Architecture & Part Numbering

A seven-gear transmission packages a high-ratio helical input stage and a long spur-gear transfer path inside a two-piece housing.

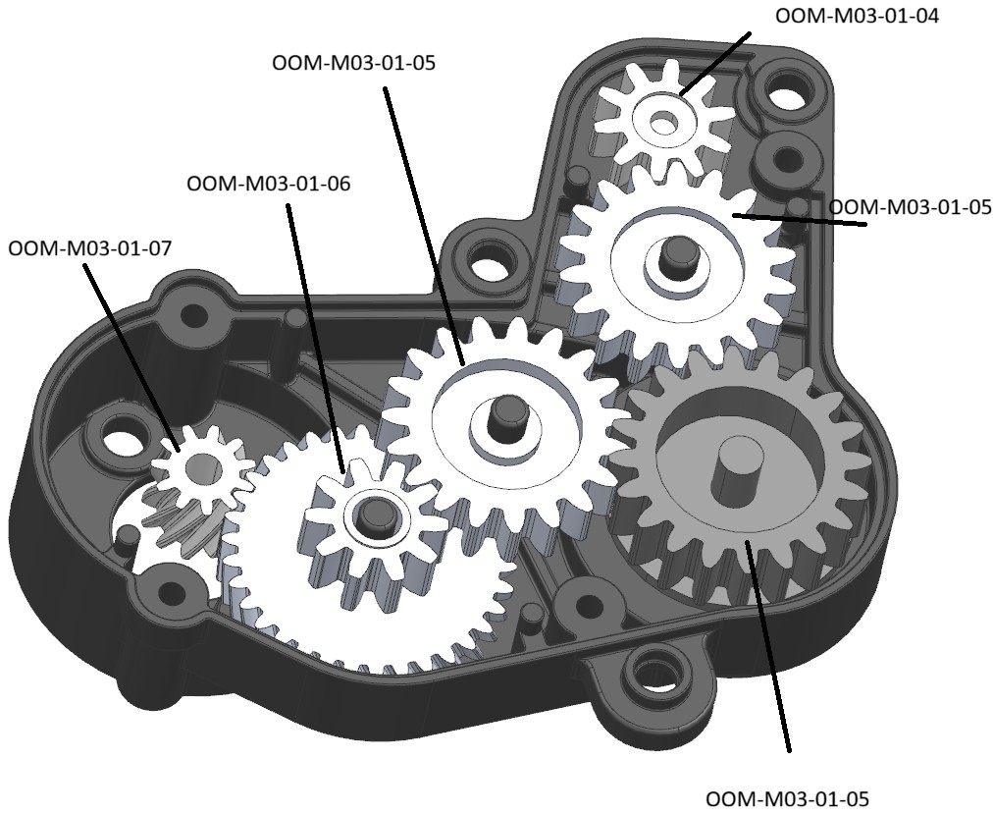
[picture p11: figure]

Figure 2. Internal OOM-M03-01 gearbox assembly with project part-code callouts.

Part code | Designation | Type | Primary role
OOM-M03-01-01 | Bottom housing | Custom housing | Motor-side shell, lower gear-support features and structural mounting bosses.
OOM-M03-01-02 | Top housing | Custom housing | Closes the gear cavity and carries the external output opening/interface.
OOM-M03-01-03 | Output drive socket | Custom coupler | Non-circular external drive interface located on the Z7 output axis.
OOM-M03-01-04 | Z7 output gear | 10-tooth spur gear | Final internal gear; drives the external output socket axis.
OOM-M03-01-05 | Intermediate gear set | Z4/Z5/Z6 spur positions | Annotated at the three intermediate spur-gear positions; tooth counts are 19T, 20T and 18T.
OOM-M03-01-06 | Compound transfer gear | Z2 helical + Z3 spur | 34T helical gear and 10T spur pinion rigidly share one axis.
OOM-M03-01-07 | Z1 motor pinion | 11-tooth helical pinion | Mounted on the RS-385PH-2466 motor shaft; gearbox input member.
RS-385PH-2466 | DC motor | Purchased motor | 12 VDC motor identification; drives Z1 directly.

PART-CODE READING / OOM-M03-01-05 is shown at the Z4, Z5 and Z6 positions. Their tooth counts are 19T, 20T and 18T respectively; use the CAD geometry for the exact position part.

# 2 Gear Train Design & Kinematics

The 3.091:1 reduction is created at the helical motor stage; the following four spur meshes route torque to the remote output axis without changing the net ratio.
3.091 : 1

OVERALL REDUCTION
motor to output

32.35 %

OUTPUT SPEED
of motor speed

## Opposite

ROTATION
motor vs. output

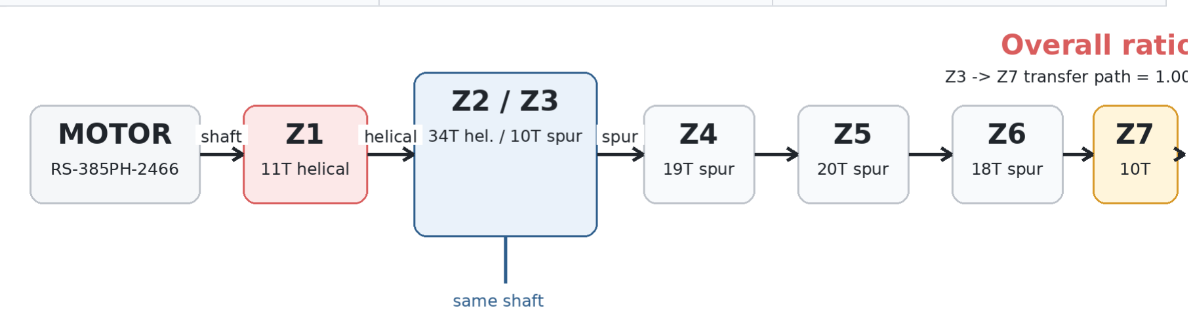
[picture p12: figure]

Figure 3. Kinematic chain. Z2 and Z3 are coaxial on the compound transfer gear.

## Stage-by-stage ratio and center distance

Stage | Mesh | Teeth | Driven/driver ratio | Center distance | Function
Z1 -> Z2 | Helical | 11 -> 34 | 34/11 = 3.0909 | 12.413 mm | Primary reduction
Z2 / Z3 | Compound axis | 34 / 10 | 1.000 | Same axis | Rigid coaxial transfer
Z3 -> Z4 | Spur | 10 -> 19 | 19/10 = 1.9000 | 11.600 mm | Transfer
Z4 -> Z5 | Spur | 19 -> 20 | 20/19 = 1.0526 | 15.600 mm | Transfer
Z5 -> Z6 | Spur | 20 -> 18 | 18/20 = 0.9000 | 15.200 mm | Transfer
Z6 -> Z7 | Spur | 18 -> 10 | 10/18 = 0.5556 | 11.200 mm | Transfer to output

## Why the intermediate train is useful

The spur path from Z3 to Z7 telescopes to Z7/Z3 = 10/10 = 1.000. In other words, Z4, Z5 and Z6 mainly relocate the torque path through the housing and around the package geometry rather than adding net reduction. The total ideal ratio therefore becomes (34/11) x (10/10) = 3.0909. Five external gear meshes are present in total, so the final output rotates opposite the motor shaft.

# 3 Gear Geometry Reference

Documented tooth parameters, derived helical-system relationships and involute reference values for CAD recreation or cross-checking.

## Helical input stage - Z1 / Z2

Gear | z | Normal m [mm] | Pressure angle | Helix angle | Pitch d [mm] | Outside da | Root df | Derived db
Z1 / OOM-M03-01-07 | 11 | 0.500 | 25 deg | 25 deg | 6.069 | 7.069 | 4.819 | 5.397
Z2 / OOM-M03-01-06 | 34 | 0.500 | 25 deg | 25 deg | 18.757 | 19.757 | 17.507 | 16.679

HELICAL-SYSTEM INTERPRETATION / The documented pitch diameters satisfy d = m_n z / cos(beta), so the 0.500 mm value behaves as a normal module. With beta = 25 deg, the derived transverse module is m_t = 0.5517 mm. Treating the 25 deg pressure angle as normal gives a transverse pressure angle of approximately 27.23 deg. Preserve the native CAD helix hand and tooth form when remaking the pair.

## Spur transfer gears - Z3 through Z7

Gear | z | Module [mm] | Pressure angle | Pitch d | Outside da | Root df | Derived db
Z3 / OOM-M03-01-06 | 10 | 0.800 | 25 deg | 8.000 | 9.600 | 6.000 | 7.250
Z4 / OOM-M03-01-05 | 19 | 0.800 | 25 deg | 15.200 | 16.800 | 13.200 | 13.776
Z5 / OOM-M03-01-05 | 20 | 0.800 | 25 deg | 16.000 | 17.600 | 14.000 | 14.501
Z6 / OOM-M03-01-05 | 18 | 0.800 | 25 deg | 14.400 | 16.000 | 12.400 | 13.051
Z7 / OOM-M03-01-04 | 10 | 0.800 | 25 deg | 8.000 | 9.600 | 6.000 | 7.250

## Reading the diameter data

- For the spur stages, the pitch diameters follow d = m z, the outside diameters follow da = d + 2m, and the documented root diameters correspond to df = d - 2.5m.
- For the helical pair, the same addendum/root offsets are applied using the 0.5 mm normal module while the pitch diameter is enlarged by 1/cos(beta).
- The involute base-circle values shown above are derived reference values (db = d cos(alpha_t) for the helical pair and db = d cos(25 deg) for the spur gears). Use the native CAD/STEP tooth profile as the manufacturing master.

# 4 Top Housing & Output Interface

OOM-M03-01-02 closes the gear cavity and locates the external OOM-M03-01-03 output socket on the final gear axis.

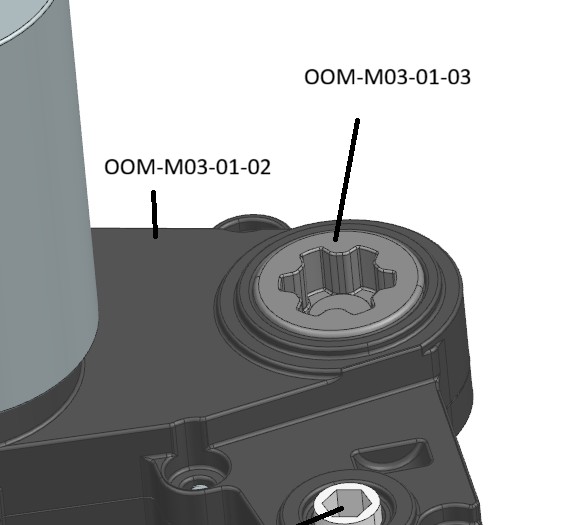
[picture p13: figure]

Figure 4. Top-housing region showing OOM-M03-01-02 and the OOM-M03-01-03 external output interface.

Feature | Type | Geometry / interface | Design role
OOM-M03-01-02 | Top housing | Perimeter shell, closure ledge, bosses and upper support features | Maintains upper-side alignment of the gear axes and encloses the transmission.
OOM-M03-01-03 | Output drive socket / coupler | Non-circular internal drive form visible in CAD | Transfers Z7 shaft torque to the external brush/actuator interface without relying on friction alone.
Z7 output axis | Gear + socket coaxial interface | 10-tooth spur gear inside, output socket outside | The internal gear axis and external coupling axis must remain concentric through the closed housing.

## Top-housing design logic

- The output opening is directly above the final gear axis, so torque exits without an offset coupler.
- The non-circular socket gives positive torque transfer. A remix may change this outer socket while preserving the Z7 axis and support geometry.
- The perimeter register and bosses preserve gear-axis spacing after closure and should not distort the output journal or remove end clearance.
- The top-housing support hardware is now identified separately: an AMC30604 metric plain Oilite bush and a CAD-defined Ø3.00 mm shaft/pin are shown in Section 6.2. Preserve their modeled locations and running clearances when remaking the cover.

# 5 Bottom Housing & Motor Interface

OOM-M03-01-01 carries the motor-side structure and establishes the alignment between the RS-385PH-2466 shaft and the helical Z1/Z2 mesh.

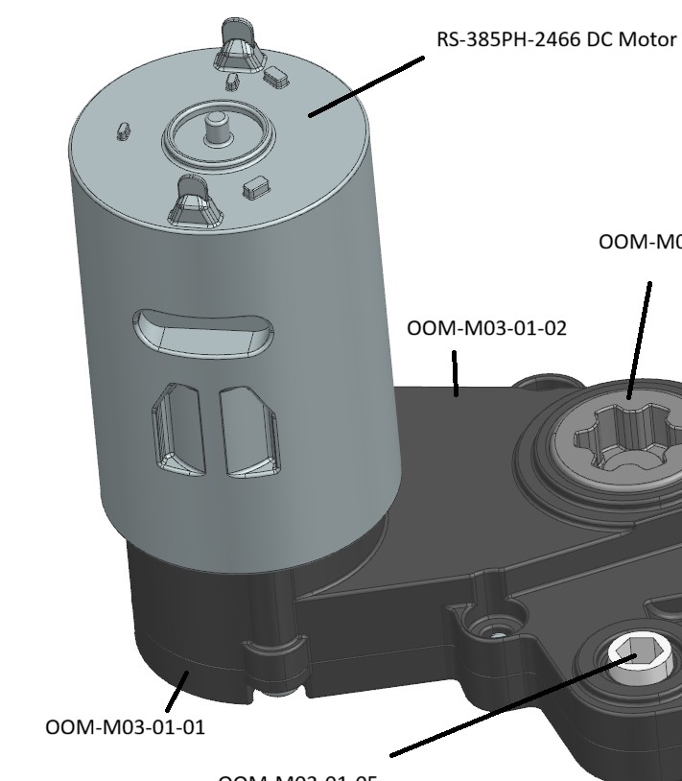
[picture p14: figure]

Figure 5. Motor-side view showing the RS-385PH-2466 motor and OOM-M03-01-01 / OOM-M03-01-02 housing interface.

Interface | Type | Reference | Design role
RS-385PH-2466 | Brushed DC motor | 12 VDC identification | Motor shaft drives Z1 directly; motor envelope and shaft location are defined by CAD.
OOM-M03-01-01 | Bottom housing | Motor cradle / lower shell and gear cavity | Reacts motor body loads, supports lower-side gear axes and provides external mounting bosses.
OOM-M03-01-07 / Z1 | 11T helical pinion | 0.5 mm normal module, 25 deg helix | Press/fit relationship to motor shaft defines the gearbox input.
Motor-to-Z2 alignment | Axis relationship | 12.413 mm nominal center distance | Controls helical mesh contact, noise and radial/axial load transfer.

MOTOR-INTERFACE RULE / Preserve the CAD motor shaft location, Z1 axial position and 12.413 mm Z1-Z2 center distance. The helical first stage creates axial thrust, so the motor bearings and compound Z2/Z3 support must retain the two gears axially as well as radially.

# 6 Shaft, Bearing, Bushing & Load-Path Architecture

How the motor bearings, purchased plain bearings, fixed shafts/posts and housing seats carry the forces created by the seven-gear train.

Axis | Support concept | Rotating member | Load-path / design interpretation
Motor / Z1 axis | Motor internal bearings | OOM-M03-01-07 pinion on motor shaft | Radial load plus helical axial thrust. Keep pinion overhang short and preserve motor axial retention.
Z2 / Z3 compound axis | Ø2.45 mm fixed shaft/post in OOM-M03-01-01 | OOM-M03-01-06 compound gear | The compound Z2/Z3 axis is located by a fixed Ø2.45 mm support shown in the bottom-housing reference. Preserve its CAD length, axis position and gear-bore running clearance.
Z4 axis | JSM-1416-05 iglidur J plain sleeve bearing | OOM-M03-01-05, 19T | 14 mm ID × 16 mm OD × 5 mm long polymer sleeve. Provides a replaceable, lubricant-free plain-bearing interface at the large-hub transfer axis.
Z5 axis | Ø2.45 mm fixed shaft/post in OOM-M03-01-01 | OOM-M03-01-05, 20T | Fixed gear axis. The 2.45 mm diameter is a design value; do not round it to 2.50 mm without rechecking the mating gear-bore clearance.
Z6 axis | Ø2.45 mm fixed shaft/post in OOM-M03-01-01 | OOM-M03-01-05, 18T | Fixed gear axis feeding the final output stage. Preserve shaft perpendicularity and CAD-defined support length.
Z7 / output axis | MR106ZZ shielded miniature ball bearing | OOM-M03-01-04 + OOM-M03-01-03 | 6 mm ID × 10 mm OD × 3 mm wide rolling bearing at the final/output support location. Maintain seat concentricity and axial retention through housing closure.

## Key geometric relationships

- Each gear-center distance is created by the housing journal/support locations. Print shrinkage or fit tuning must not move those axes independently.
- The Z2/Z3 compound gear is the kinematic hinge between the helical and spur systems. Any angular or radial play at this axis affects both the motor mesh and the entire downstream transfer path.
- Axial clearance is needed on every rotating gear so closing the housing does not create face rubbing. The helical Z2 member additionally needs a positive thrust reaction path.
- The three OOM-M03-01-05 positions should be checked individually because their tooth counts differ even though the annotated view groups them under one project code.
- Treat every support as a complete tribological interface: purchased bearing/bushing, shaft or hub diameter, housing seat, axial retention and clearance must remain compatible. Use the CAD for support lengths and axial stack-up, and the selected supplier catalogue for purchased-part tolerances.
LOAD-PATH SUMMARY / Motor torque enters through Z1, is reduced at Z1-Z2, passes coaxially from Z2 to Z3,
then follows Z4-Z5-Z6 to Z7 and the output socket. The housings absorb the radial separating forces at every
mesh, the helical thrust at the first stage, and the external output reaction through their bosses and mounting interfaces.

# 6.1 Bottom Housing Support Hardware

OOM-M03-01-01 carries three fixed Ø2.45 mm gear-support shafts/posts together with the MR106ZZ rolling bearing and the JSM-1416-05 polymer plain bearing. These parts convert the printed housing from a simple shell into the primary lower-side datum for the transmission axes.

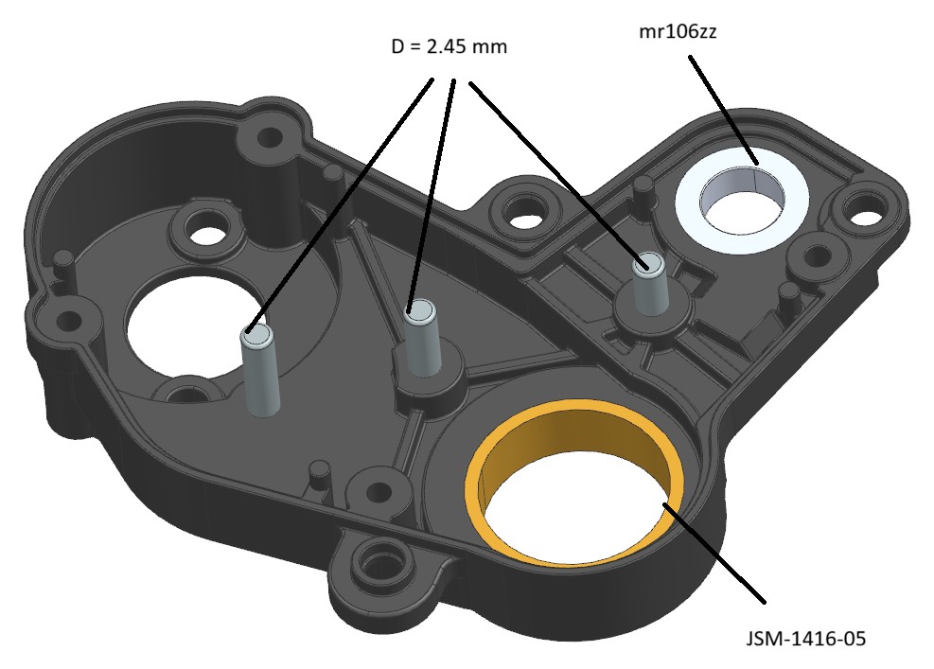
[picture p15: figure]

Figure 6. Bottom-housing support hardware: three Ø2.45 mm fixed shaft locations, MR106ZZ miniature ball bearing and JSM-1416-05 iglidur J sleeve bearing.

Component | Type | Nominal size | Qty | Design use
MR106ZZ | Shielded miniature deep-
| groove ball bearing | 6 mm ID × 10 mm OD × 3 mm
| | W | 1 | Rolling support at the CAD-
| | | | defined final/output-side axis.
| | | | Standard metal shields retain
| | | | lubricant and limit debris
| | | | entry.
JSM-1416-05 | igus iglidur J cylindrical plain
| bearing | 14 mm ID × 16 mm OD × 5
| | mm L | 1 | Large-diameter plain-bearing
| | | | support. Lubricant-free
| | | | polymer sleeve is press-fitted
| | | | into the housing seat and
| | | | runs on the mating 14 mm
| | | | hub/shaft surface.
Ø2.45 mm shafts/posts | Fixed gear shafts / pins | Ø2.45 mm; length per CAD | 3

Locate three internal rotating members. Preserve the exact diameter and
perpendicularity; do not
substitute Ø2.50 mm without checking gear-bore clearance. CATALOG FIT NOTE / JSM-1416-05 is a 14 × 16 × 5 mm iglidur J sleeve. Manufacturer catalogues specify the finished running fit only after press-fit; printed housing variants should tune the bearing seat with a local fit coupon rather than scaling the complete housing.

# 6.2 Top Housing Support Hardware

The inside face of OOM-M03-01-02 adds a compact Oilite sleeve-bearing location and a separate Ø3.00 mm shaft/pin. Together with the bottom-housing supports, these features close the axial stack and provide replaceable wear surfaces where direct plastic-on-shaft contact would otherwise dominate.

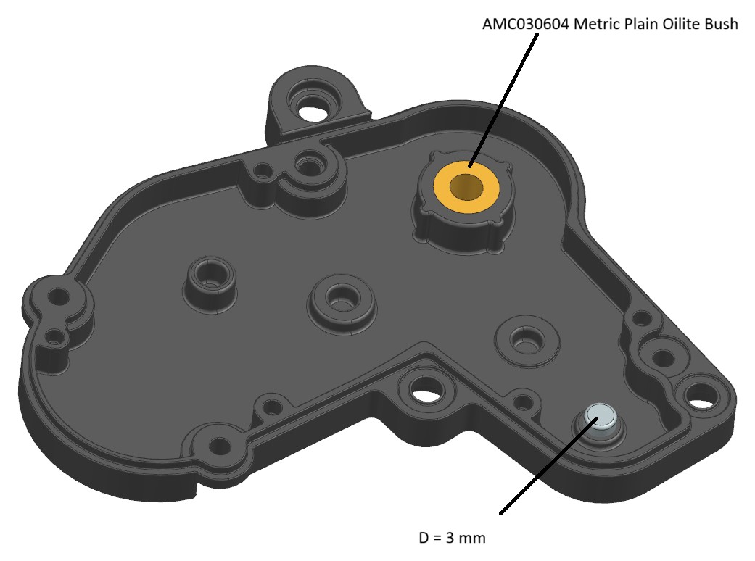
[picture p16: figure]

Figure 7. Top-housing support hardware: AMC30604 metric plain Oilite bush and CAD-defined Ø3.00 mm shaft/pin location.

Component | Type | Nominal size | Qty | Design use
AMC30604 | Metric plain Oilite bush | Nominal 3 mm ID × 6 mm OD
× 4 mm L | 1

Self-lubricating sinteredbronze sleeve at the
annotated top-housing
support boss. Supplier codes may vary; preserve the 3 × 6 × 4 mm geometry and
Oilite/plain-bearing function.
Ø3.00 mm shaft/pin | Fixed shaft / pin | Ø3.00 mm; length per CAD | 1

Mating support shaft shown in the top housing. Axial length and end condition are CADcontrolled; confirm running clearance against the selected bushing supplier tolerance.

## Support-interface rules

- Do not treat bearing OD, bushing OD and shaft diameter as independent dimensions: the housing seat, press fit, running fit and axial retention form one tolerance chain.
- The annotated CAD calls the bronze sleeve AMC30604. A 3 × 6 × 4 mm metric Oilite sleeve is a standard catalogue geometry, but supplier-specific part numbers and tolerance systems can differ.
- Shaft lengths and materials are not specified by the annotated support views; use the current CAD/BOM for those values rather than inferring them from the diameter callouts.

# 7 BOM, Assembly & Manufacturing Notes

Core parts and a practical build sequence for community reproductions and CAD remixes.

Item | Part no. | Description | Qty | Origin | Design detail
1 | OOM-M03-01-01 | Bottom housing | 1 | Custom CAD | Motor-side shell and lower support features
2 | OOM-M03-01-02 | Top housing | 1 | Custom CAD | Upper shell and output-interface region
3 | OOM-M03-01-03 | Output drive socket / coupler | 1 | Custom CAD | External positive-drive interface on Z7 axis
4 | OOM-M03-01-04 | Z7 final output gear, 10T | 1 | Custom CAD | m 0.8 spur; final internal gear
5 | OOM-M03-01-05 | Intermediate spur gear positions Z4/Z5/Z6 | 3 positions | Custom CAD | 19T / 20T / 18T; use exact CAD per position
6 | OOM-M03-01-06 | Compound Z2/Z3 transfer gear | 1 | Custom CAD | 34T helical + 10T spur on one axis
7 | OOM-M03-01-07 | Z1 motor pinion, 11T | 1 | Custom CAD | m_n 0.5; beta 25 deg; motor shaft input
8 | RS-385PH-2466 | Brushed DC motor | 1 | Purchased | 12 VDC identification; CAD defines fit
9 | MR106ZZ | Miniature shielded ball bearing | 1 | Purchased | 6 × 10 × 3 mm; bottom-housing rolling support
10 | JSM-1416-05 | iglidur J cylindrical plain bearing | 1 | Purchased | 14 × 16 × 5 mm; lubricant- free polymer sleeve
11 | AMC30604 | Metric plain Oilite bush | 1 | Purchased | Nominal 3 × 6 × 4 mm; top- housing sleeve bearing
12 | CAD-defined Ø2.45 shafts | Fixed gear shafts / pins | 3 | Cut to CAD length | Ø2.45 mm; preserve diameter and perpendicularity
13 | CAD-defined Ø3.00 shaft | Fixed shaft / pin | 1 | Cut to CAD length | Ø3.00 mm; length/end condition per CAD

## Suggested assembly sequence

1. Inspect the housing journal/post surfaces, gear bores and motor pocket; remove only intentional support material or debris from functional surfaces.
2. If the Z1 pinion is installed separately, fit OOM-M03-01-07 to the RS-385PH-2466 shaft using the CAD axial position and a method that does not hammer load through the motor bearings.
3. Seat the motor in OOM-M03-01-01 and place the OOM-M03-01-06 compound Z2/Z3 gear so the helical teeth enter mesh without forcing.
4. Install Z4, Z5 and Z6 in their CAD-defined positions, then install Z7 and engage the OOM-M03-01-03 output socket/shaft relationship as modeled.
5. Close OOM-M03-01-02 lightly and rotate the train by hand through several revolutions. Expect motor cogging, but no hard gear interference, housing rub or tight spots.
6. Tighten the housing evenly using the current CAD/BOM fastener strategy, repeat the rotation check, then begin powered run-in at reduced voltage before full-load use.

## Manufacturing and modification notes

- Preserve the helical gear hand, 25 deg helix angle, normal module and compound Z2/Z3 coaxial relationship when moving the design between CAD systems.
- Do not assume the three OOM-M03-01-05 gear positions are geometrically identical; their tooth counts and centerdistance roles differ.
- If journal fits are printed, tune them with process-specific coupons rather than globally scaling the entire housing.
- Record material, print process, orientation, post-cure and dimensional compensation for gears and housings so another builder can reproduce the same behavior.
- Use only a small compatible gear lubricant if lubrication is required; keep it away from motor commutator openings and any plain-bearing material that should run dry.

# 8 Community Build Notes & References

A compact checklist for downloading the CAD, reproducing the gearbox or adapting the motor/output interfaces.

## What to look for after assembly

Check | What the builder should observe
Motor alignment | Z1 should enter the Z2 helical mesh evenly across the intended face width; no visible skew or end contact.
Helical mesh | Rotate slowly and confirm no hard spot. The first stage carries both radial force and axial thrust.
Compound axis | Z2 and Z3 should run as one coaxial member without wobble between the helical and spur stages.
Transfer path | Z4-Z5-Z6 should rotate freely and preserve positive backlash around the full revolution.
Output axis | OOM-M03-01-03 should remain concentric with Z7 and rotate without rubbing the top housing.
Housing closure | Fastening the two shells should not significantly increase rotation torque or create gear-face rub.
Run-in | Start at reduced voltage, record sound/current, then inspect teeth, journals and housing witness marks.
Remix documentation | Record any changed motor, shaft, journal, gear or socket dimensions so the modified version is reproducible.

## Design reference measurements

Characteristic | Design reference | Note
Z1-Z2 center distance | 12.413 mm | Helical stage
Z3-Z4 center distance | 11.600 mm | Spur stage
Z4-Z5 center distance | 15.600 mm | Spur stage
Z5-Z6 center distance | 15.200 mm | Spur stage
Z6-Z7 center distance | 11.200 mm | Spur stage
Overall ideal ratio | 3.0909 : 1 | Output speed = 32.35% of motor speed

## References and project links

[1] OOMWOO One CAD repository - https://github.com/makerspet/oomwoo-one-cad
[2] OOMWOO One CAD 3D design specification - https://github.com/makerspet/oomwoo-one-cad/blob/main/docs/SPEC.md
[3] OOMWOO main project BOM and design documentation - https://github.com/makerspet/oomwoo
[4] Mabuchi Motor RS-385PH family product information - https://product.mabuchi-motor.com/
[5] IEC 60335 appliance test documentation identifying RS-385PH-2466 as a 12 VDC motor (Roborock appliance component list).
[6] SMB Bearings - MR106ZZ miniature shielded radial ball bearing data sheet; 6 mm bore × 10 mm OD × 3 mm width.
[7] igus - iglidur J JSM-1416-05 cylindrical plain bearing; 14 mm ID × 16 mm OD × 5 mm length.
[8] Oilite - M-Series metric 3 × 6 × 4 mm sleeve-bearing catalogue geometry (supplier-specific part numbering varies; annotated CAD identifier: AMC30604).
REPOSITORY NOTE / For current license terms, contribution guidance, part revisions and manufacturing geometry, use the repository README, LICENSE and native CAD files. This PDF is an explanatory design reference, not a substitute for the current CAD revision.

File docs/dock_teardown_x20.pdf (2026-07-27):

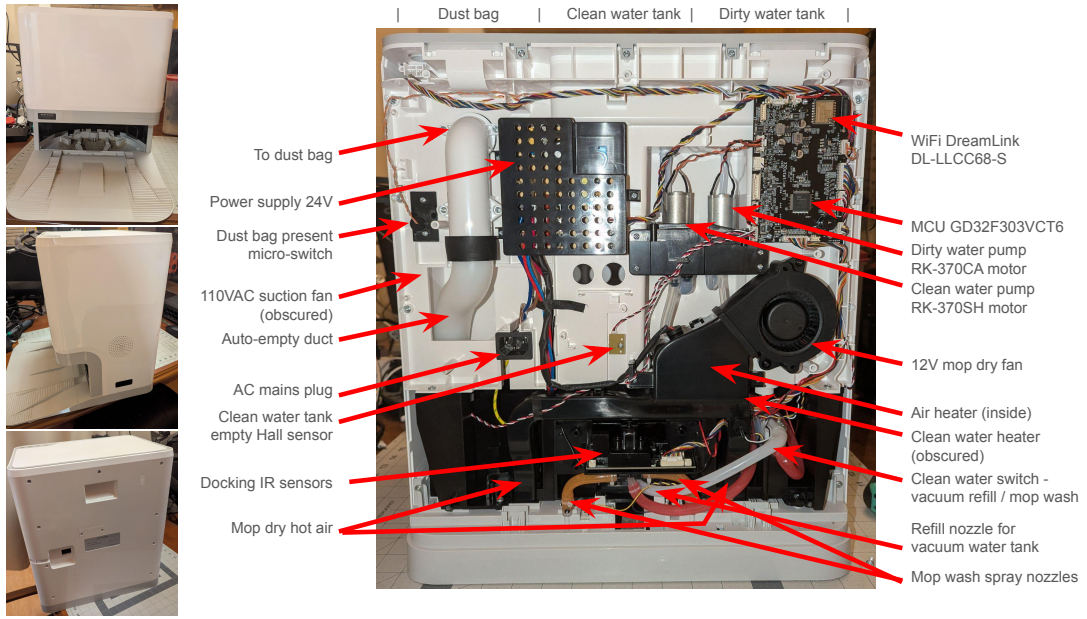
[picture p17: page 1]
Power supply 24V; WiFi DreamLink DL-LLCC68-S; Dust bag; Clean water tank |; Dirty water tank

To dust bag

MCU GD32F303VCT6
Dirty water pump
RK-370CA motor
Clean water pump

Dust bag present
micro-switch

RK-370SH motor 110VAC suction fan

(obscured)
Auto-empty duct

12V mop dry fan

AC mains plug
Clean water tank
empty Hall sensor

Air heater (inside)
Clean water heater
Clean water switch -
vacuum refill / mop wash

Docking IR sensors

Mop dry hot air

Refill nozzle for
vacuum water tank

Mop wash spray nozzles

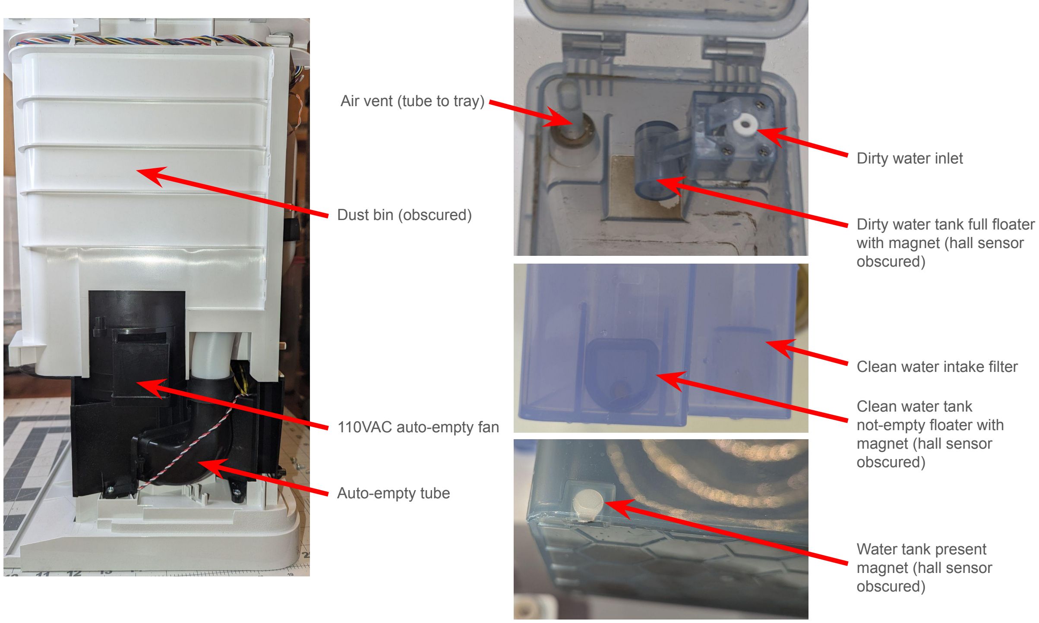
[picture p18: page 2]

Auto-empty tube

110VAC auto-empty fan

Dust bin (obscured) | Dirty water tank full floater
| with magnet (hall sensor obscured)

Air vent (tube to tray)

Clean water tank
not-empty floater with
magnet (hall sensor
obscured)

Clean water intake filter

Dirty water inlet

Water tank present
magnet (hall sensor
obscured)

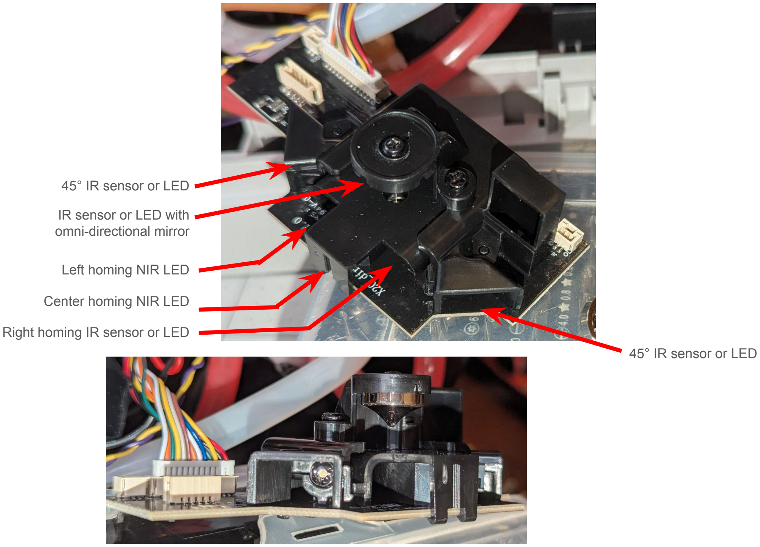
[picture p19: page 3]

45° IR sensor or LED

45° IR sensor or LED

Left homing NIR LED

Right homing IR sensor or LED

Center homing NIR LED

IR sensor or LED with
omni-directional mirror

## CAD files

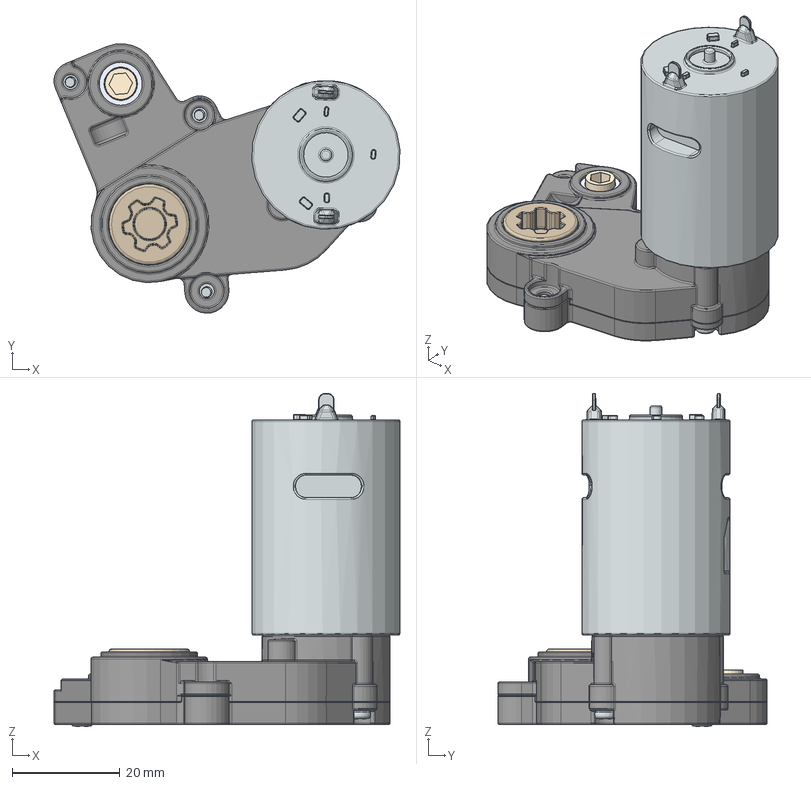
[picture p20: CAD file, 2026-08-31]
fuison360/STEP/03-01 Motor_Gearbox.step
64.1 x 49.9 x 61.8 mm
M2 x 9
RS-385PH-2466 DC Motor
OOM-M03-01-07
shaft3-030102
shaft2-030102
shaft1-030102
JSM-1416-05_stp
bearing_mr106zz_0_x_t_stp
OOM-M03-02-05_step
OOM-M03-01-06_STANDARD_GEAR_step6228
OOM-M03-01-04_step73038
OOM-M03-01-05_step
AMC030604 Metric Plain Oilite Bush
shaft-030101
OOM-M03-01-03_step101114

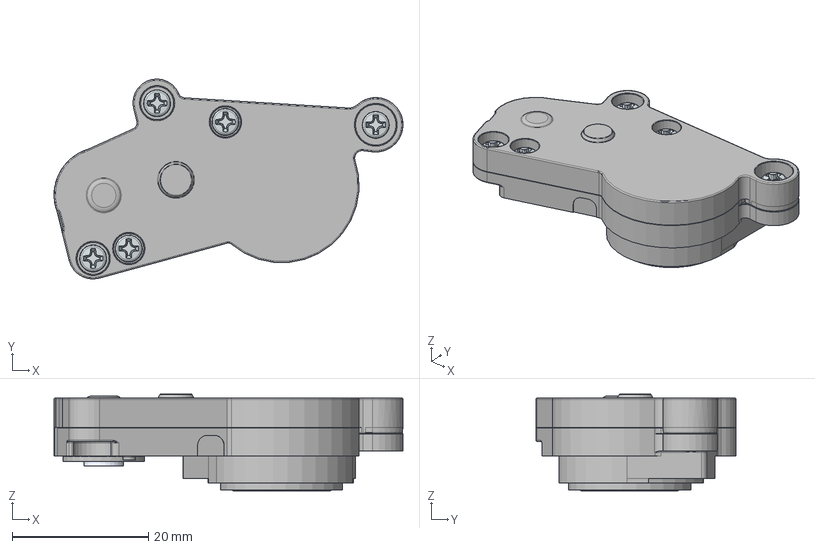
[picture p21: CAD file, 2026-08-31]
fuison360/STEP/03-02 Red_Brush_Gearbox_step.step
51.3 x 29.4 x 14.2 mm
JSM-1416-05_stp
shaft-3_stp
bronze-sae841-sleeve-bearing-AM-306-5
shaft-1
M2 x 5
OOM-M03-02-05_step
OOM-M03-02-04
OOM-M03-02-03_step

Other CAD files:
fuison360/03-01 Motor_Gearbox.f3d
fuison360/03-02 Red_Brush_Gearbox_step.f3d
fuison360/Assembly_2.f3z
fuison360/C01 Top Assembly.f3d
fuison360/C01_2_base_snapshot.f3d
fuison360/OOM-M02-Assembly.f3d
fuison360/Top_Assembly_081426a.f3z

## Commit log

2026-07-08 Add LiDAR models
2026-07-09 Add Raspberry Pi CM4, CM5
2026-07-16 Add specifications for OOMWOO One mop robot
    Document specifications for the OOMWOO One consumer mop robot design, including details on brushes, mops, charging contacts, and sensors.
2026-07-23 Add iRobot caster wheel to lib/casters
    Add a STEP model of the front-center caster wheel called for in
    docs/SPEC.md, modeled from a physical iRobot front caster (Roomba e/i
    series; fits i7, i3, j7, e5, e6). Includes a category README with an
    aftermarket purchase link, following the lib/ convention.
2026-07-27 Measured tubing from dock teardown
    Removed outdated specifications and clarified the use of components in the dock design.
2026-07-27 Revise battery pack and dock specifications
    Updated specifications for battery pack and dock, including power requirements and design considerations.
2026-07-27 Dock teardown; cliff/bumper sensors pinout
2026-07-28 Dock canister sensors
    Updated specifications and details for the dock, including power requirements, tubing sizes, and sensor information.
2026-07-29 OOM-E01
    BRR-2P4S-6800 mAh
2026-07-29 OOM-P03 Mop Pad Bracket
    OOM-P03 Mop Pad Bracket
2026-07-30 OOM-B02_Side-brush-3-arm
    OOM-B02_Side-brush-3-arm
2026-07-31 OOM-E05_Carpet-sensor
    OOM-E05_Carpet-sensor
2026-08-01 OOM-E03-01_Cliff-bumper-sensor-Enclosure
    OOM-E03-01_Cliff-bumper-sensor-Enclosure
2026-08-02 OOM-W01_Drive-wheel-assy-pair
    OOM-W01_Drive-wheel-assy-pair
2026-08-02 OOM-P01_Mop-motor-module-big
    OOM-P01_Mop-motor-module-big
2026-08-04 OV5647 camera
2026-08-04 KY-003 hall sensor
2026-08-04 SPDT switches
2026-08-08 OOM-E03_Cliff-bumper-sensor-set
    OOM-E03_Cliff-bumper-sensor-set
2026-08-08 OOM-P02_Mop-motor-module-small
    OOM-P02_Mop-motor-module-small
2026-08-08 OOM-M02_Side-brush-motor-FlexiArm-extendable
    OOM-M02_Side-brush-motor-FlexiArm-extendable
2026-08-09 OOM-M01_Main-brush-motor-gearbox
    OOM-M01_Main-brush-motor-gearbox
2026-08-14 Fusion360 source
    [Top_Assembly_081426a.f3z]
2026-08-15 OOM-W01-02 Wheel Switch
    OOM-W01-02 Wheel Switch
2026-08-25 Revise LiDAR and mop specifications in SPEC.md
    Updated specifications for LiDAR placement and mop lifting requirements.
2026-08-29 Add mops
    [Assembly_2.f3z]
2026-08-31 Main brush gearboxes
    [03-01 Motor_Gearbox.f3d, 03-01 Motor_Gearbox.step, 03-02 Red_Brush_Gearbox_step.f3d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]
2026-08-31 Main brush gearbox documentation
2026-09-03 Base snapshot WIP
    [C01_2_base_snapshot.f3d]
2026-09-08 Vacuum assembly, updated base, side brush arm
    [C01 Top Assembly.f3d, OOM-M02-Assembly.f3d]
2026-09-08 Side brush assembly design instructions
    Updated specifications for mop motor assembly, obstacle avoidance camera, bagless vs bag dock options, and auto-empty design recommendations.
2026-09-25 Add suction fan mount, 22N704V160 fan

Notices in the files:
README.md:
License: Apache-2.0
